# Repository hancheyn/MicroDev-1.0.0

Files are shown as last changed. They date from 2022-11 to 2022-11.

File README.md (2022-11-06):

# MicroDev Development Board Tester Setup

## Raspbian Setup
- Download Raspbian OS Imager (https://www.raspberrypi.com/software/)
- Insert and locate SD card on computer
- Install Recommended Raspberry Pi OS (w/ Software) to SD card.
- Boot-up Raspi
- Username: microdev | Password: microdev
- Connect to Internet
- Terminal: git clone https://github.com/hancheyn/MicroDev.git
- Terminal: chmod 777 MicroDev/setup.sh
- Terminal: ./MicroDev/setup.sh
- File Manager > Edit > Preferences > Volume Management > 
[uncheck] Show available options for removable media when they are inserted
- Raspberry Pi Configuration > [disable] Screen Blanking

## Arduino CLI Installation & Application
Start up raspberry pi using an hdmi monitor, keyboard, and mouse.

    Download in Add/Remove Software:
- Raspberry OS Start Menu > Preferences > Add/Remove Software
- Search “arduino”
- Check AVR development board IDE
- Check Command Line Tool for compiling Arduino Sketches
- Click Apply and Wait for Download. 

    Download in Terminal:
- Terminal: curl -fsSL https://raw.githubusercontent.com/arduino/arduino-cli/master/install.sh | sh
- Put arduino-cli into a runnable folder so the command will run on its own ($PATH).
- Terminal Command: arduino-cli core install arduino:avr
- Terminal Command View Connected Boards: arduino-cli board list
- Terminal Command Compile .ino example: arduino-cli compile -b arduino:avr:uno Blink.ino -e
- Terminal Command Upload .ino example: arduino-cli upload -b arduino:avr:uno -p /dev/ttyACM0 Blink.ino

### FLASH TO ARDUINO NOTES:
The Arduino CLI does not automatically create a permanent bit file for uploading. In order to do this, one must add the command ‘-e’ while compiling. This looks like the following: arduino-cli compile -b arduino:avr:uno Blink.ino -e.This will create a new folder within the arduino project folder that contains a bit file, “[Project name].ino.with_bootloader.bin”. This should be in a folder with a file path ./build/arduino.avr.uno/. In Terminal, the command arduino-cli upload -b arduino:avr:uno -p /dev/ttyACM0 -i [binary file path] will upload the file.
    
STM32 CLI Installation & Application
Start up raspberry pi using an hdmi monitor, keyboard, and mouse.

    Download in Add/Remove Software:
- Raspberry OS Start Menu  > Preferences > Add/Remove Software
- Search “stlink”
- Check OpenSource ST-Link tools replacement… (x3)
  - …libstlink1-1.6.1+ds-3
  - …stlink-gui-1.6.1+ds-3
  - …stlink-tools-1.6.1+ds-3

- Click Apply and Wait for Download 

### FLASH TO STM32 NOTES:
The STMCubeIDE does not automatically create a permanent bit file for uploading. Since it uses a .elf file (located in the debug folder) this must first be converted to a .bin file before flashing can occur. The .elf file can be converted using the following command from terminal arm-none-eabi-objcopy -O binary F401RE_T.elf main.bin. In the previous example, F401RE_T.elf becomes a binary file called main.bin. Flashing can then occur using the command st-flash write main.bin 0x08000000.

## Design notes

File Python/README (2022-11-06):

README

TEST CONFIGURATION
Test ID 1 => GPIO Output Voltage (under load)
Test ID 2 => GPIO Output Pin Internal Resistance
Test ID 3 => GPIO Input Pull-Up Voltage
Test ID 4 => GPIO Input Pull-Down Voltage (STM Only)
Test ID 5 => ADC Analog Read
Test ID 6 => 5.0V Supply Pin Voltage Output
Test ID 7 => 3.3V Supply Pin Voltage Output
Test ID 8 => Power Modes
Test ID 9 => Power Mode Wakeup

KEY:
E [Enable Number]
M [Mux Address]

PIN CONFIGURATION
Pin ID 1  => E1M0   | PD2 (STM)
Pin ID 2  => E1M1   | PC12 (STM)
Pin ID 3  => E1M2   | PC11 (STM)
Pin ID 4  => E1M3   | PC10 (STM)
Pin ID 5  => E1M4   | D15 (Arduino) / PB8 (STM)
Pin ID 6  => E1M5   | PC6 (STM)
Pin ID 7  => E1M6   | PC9 (STM)
Pin ID 8  => E1M7   | PC8 (STM)
Pin ID 9  => E2M0   | REF (Arduino) / IOREF (STM)
Pin ID 10 => E2M1   | BOOT0 (STM)
Pin ID 11 => E2M2   | E5V (STM)
Pin ID 12 => E2M3   | VDD (STM)
Pin ID 13 => E2M4   | AVDD (Arduino) / AVDD (STM)
Pin ID 14 => E2M5   | U5V (STM)
Pin ID 15 => E2M6   | D14 (Arduino) / PB9 (STM)
Pin ID 16 => E2M7   | PC5 (STM)
Pin ID 17 => E3M0   | PA14 (STM)
Pin ID 18 => E3M1   | 3V3 (Arduino) / +3.3 (STM)
Pin ID 19 => E3M2   | PA13 (STM)
Pin ID 20 => E3M3   | RESET (Arduino) / RESET (STM)
Pin ID 21 => E3M4   | D12 (Arduino) / PA6 (STM)
Pin ID 22 => E3M5   | PA11 (STM)
Pin ID 23 => E3M6   | D13 (Arduino) / PA5 (STM)
Pin ID 24 => E3M7   | PA12 (STM)
Pin ID 25 => E4M0   | PC13 (STM)
Pin ID 26 => E4M1   | PB7 (STM)
Pin ID 27 => E4M2   | PA15 (STM)
Pin ID 28 => E4M3   | 5V (Arduino) / +5V (STM)
Pin ID 29 => E4M4   | PB2 (STM)
Pin ID 30 => E4M5   | D10 (Arduino) / PB6 (STM)
Pin ID 31 => E4M6   | PB12 (STM)
Pin ID 32 => E4M7   | D11 (Arduino) / PA7 (STM)
Pin ID 33 => E5M0   | PC15 (STM)
Pin ID 34 => E5M1   | A0 (Arduino) / PA0 (STM)
Pin ID 35 => E5M2   | PC14 (STM)
Pin ID 36 => E5M3   | VIN (Arduino) / VIN (STM)
Pin ID 37 => E5M4   | D7 (Arduino) / PA8 (STM)
Pin ID 38 => E5M5   | PB1 (STM)
Pin ID 39 => E5M6   | D8 (Arduino) / PA9 (STM)
Pin ID 40 => E5M7   | D9 (Arduino) / PC7 (STM)
Pin ID 41 => E6M0   | PH1 (STM)
Pin ID 42 => E6M1   | A2 (Arduino) / PA4 (STM)
Pin ID 43 => E6M2   | PH0 (STM)
Pin ID 44 => E6M3   | A1 (Arduino) / PA1 (STM)
Pin ID 45 => E6M4   | D5 (Arduino) / PB4 (STM)
Pin ID 46 => E6M5   | PB14 (STM)
Pin ID 47 => E6M6   | D6 (Arduino) / PB10 (STM)
Pin ID 48 => E6M7   | PB15 (STM)
Pin ID 49 => E7M0   | PC2 (STM)
Pin ID 50 => E7M1   | A4 (Arduino) / PC1 (STM)
Pin ID 51 => E7M2   | VBAT (STM)
Pin ID 52 => E7M3   | A3 (Arduino) / PB0 (STM)
Pin ID 53 => E7M4   | D3 (Arduino) / PB3 (STM)
Pin ID 54 => E7M5   | AGND (STM)
Pin ID 55 => E7M6   | D4 (Arduino) / PB5 (STM)
Pin ID 56 => E7M7   | PB13 (STM)

Pin ID 57 => E8M2   | PC3 (STM)
Pin ID 58 => E8M3   | A5 (Arduino) / PC0 (STM)
Pin ID 59 => E8M4   | D0 (Arduino) / PA3 (STM)
Pin ID 60 => E8M5   | D1 (Arduino) / PA2 (STM)
Pin ID 61 => E8M6   | D2 (Arduino) / PA10 (STM)
Pin ID 62 => E8M7   | PC4 (STM)

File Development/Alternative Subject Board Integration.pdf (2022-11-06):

# Alternative Subject Board Integration

A top-down approach to repurposing the MicroDev code base and hardware for an unsupported subject board. WARNING: Adding or altering code may affect functionality of the MicroDev device as a whole.

## New Development Board Footprint

The MicroDev system can be adapted for a development board with less than 62 pins to be under test. In order to connect a new board, it must be made to connect through a usb port for serial communication and an adapter must be created to connect the Littlefoot to the development board footprint.

A simple way to do that would be to use an Arduino Prototyping Board as seen below, and soldering on headers to connect to the alternative development boards design:

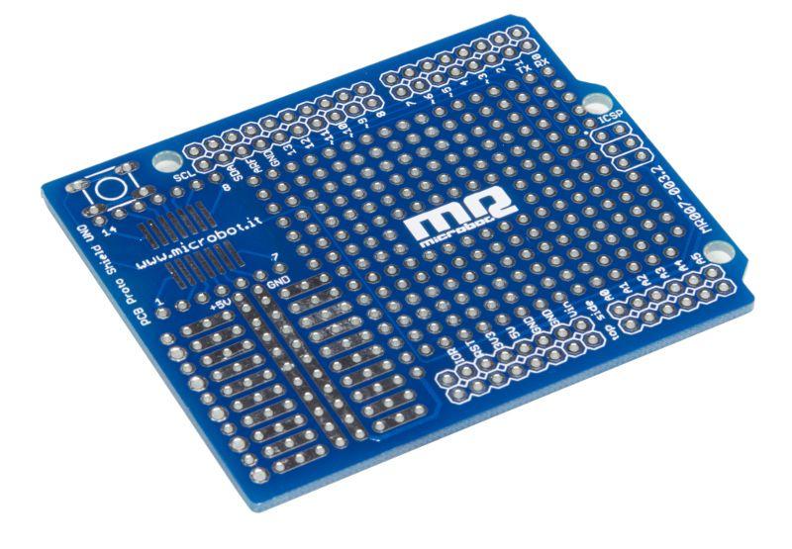
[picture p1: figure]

Figure 1: Arduino Prototyping Board

Or, a generic prototyping board to fit over the STM connection to the Littlefoot PCB on the MicroDev device.

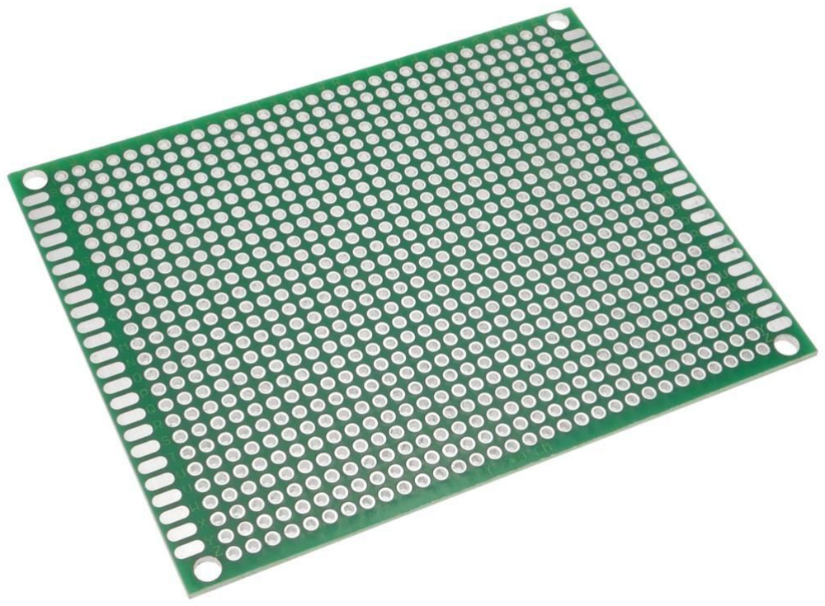
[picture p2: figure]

Figure 2: Generic PCB

### 3.3 Volt and 5 Volt Output Pin ID’s

The 3.3 Volt and 5 Volt output pins are configured to a specific multiplexer address. That means that the new footprint should connect the 3V3 pin and 5V pin of the new development board to the same place as the STM Nucleo and Arduino Uno. This could also be altered in the software by changing the functions that are contained in the Model.py module.

## Command Line Interface Alterations

If the board is an alternate STM Nucleo with the same footprint then only step the Board Identification and upload must be added in connection to the same configuration files of the other STM Nucleos. All code for the command line interface is within the Model.py module.

Board Identification and Upload

A new subject board will not be properly identified unless a command line interface compatible with the new development board is installed and configured. This command line interface must be able to identify the subject board through a unique ID, compile the embedded code, and also flash to the development board.

The identification of the connected development board is checked in a loop calling the board_list function. This function is in the Model.py module. The command line interface instruction receives an array of strings back from the subprocess call in Python. Below in Code Snippet 1, is an example of how the information is parsed to identify an Arduino Uno is connected.

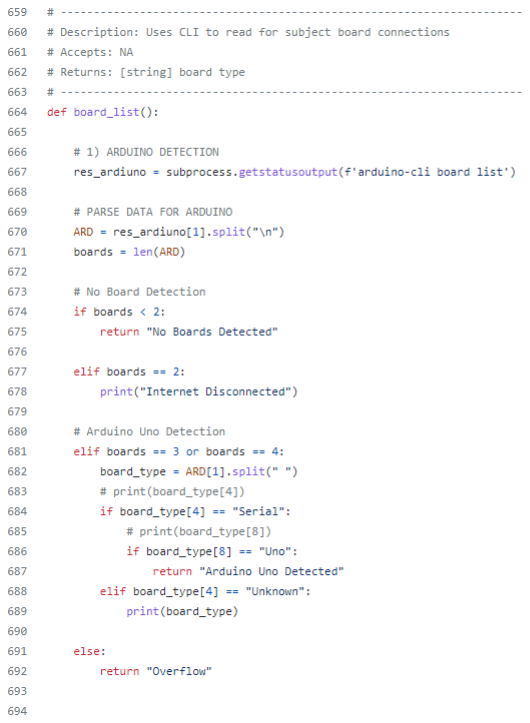
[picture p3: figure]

Code Snippet 1

The conditions for identifying the new subject board should be added after the other boards' conditionals. If nothing else is connected it will pass through those conditions and reach the connected subject board's CLI call. That should be inserted in the lines shown below in Code Snippet 2. The string that is returned after a successful detection has a place in the Controller module that is described in the pin mapping section.

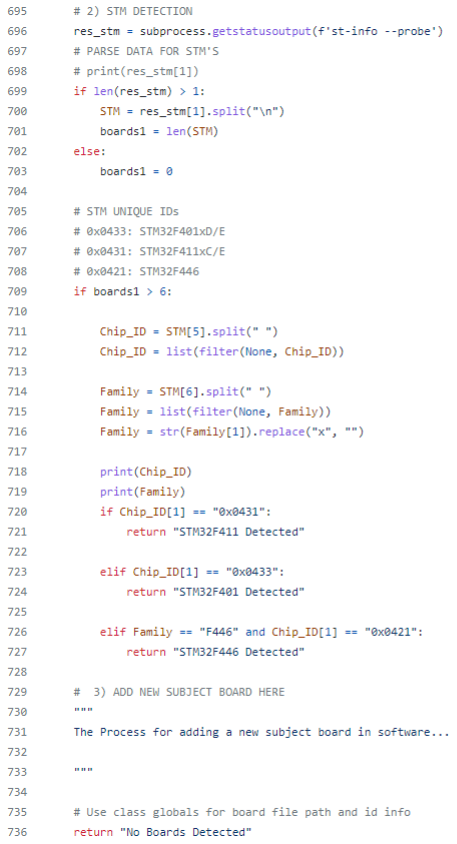
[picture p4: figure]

Code Snippet 2

## Pin Mapping and Configurations

Understanding the Pin Map

The pin map connects a pin identification number, that is used in serial communication, to the multiplexer enable signal and address signals that relate to that pin. The littlefoot PCB uses those enable signals and address signals to isolate a pin to be tested. If this pin mapping is incorrect it can be difficult to debug. The enable signals control the enable pins on each of the eight multiplexers. Only one is enabled at a time. The address signals are a 0 through 7 binary address sent via output signals to control the enabled multiplexer. The disabled multiplexer will not react to the signals even though they are all on the same bus. All code dealing with the configurations is within the Controller.py module.

Use the STM32 Nucleo Pin Map in Figure 3 as a guide to writing a new pin map.

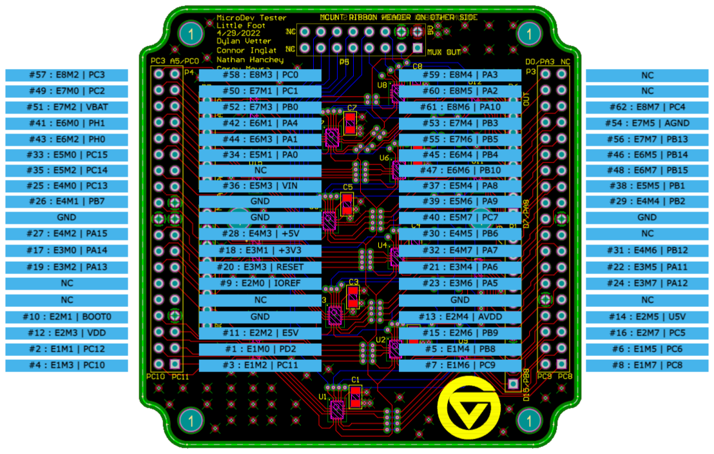
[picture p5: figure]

Figure 3: STM Nucleo Pin Mapping

The Pin IDs must be consistent between the test configuration file and the embedded C code receiving the pin ID value.

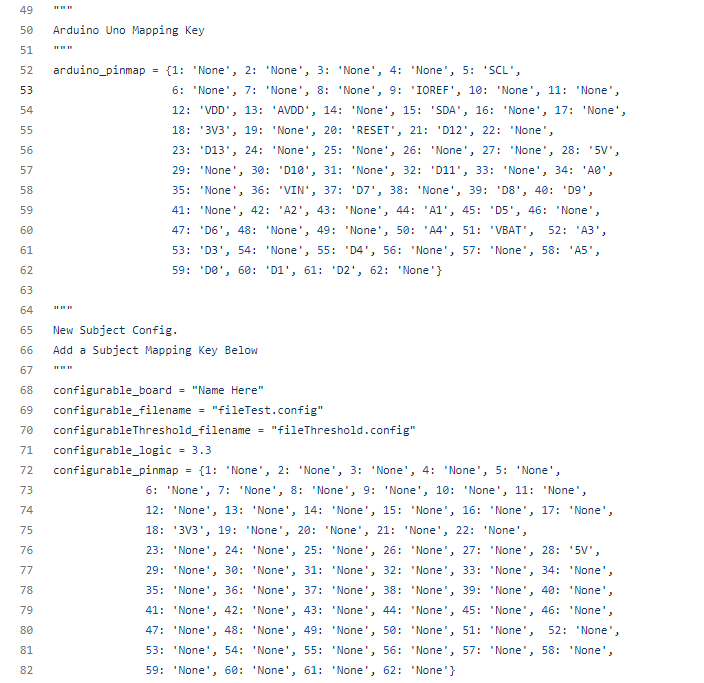
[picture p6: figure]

Code Snippet 3

The string configurable_board, seen in Code Snippet 3, must be the same string that is returned from the board_list function added in Model.py. The high logic level of the new subject development board is to be written as the configurable_logic. The string for the threshold filename, configurableThreshold_filename, and test filenames, configurable_filename, must exist in the project Python folder.

The threshold file is setup as follows:

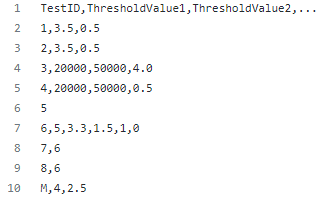
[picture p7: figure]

Code Snippet 4

After the first line, each following line is the test thresholds that will be used as the pass or fail conditions of the test. The first line describes the threshold configuration format, an improperly formatted threshold file will end the testing process. Every line shown above must be in the threshold file just as shown in Code Snippet 4. The second line represents Test #1 and each following line must be the next consecutive Test ID. M, or miscellaneous, goes on line 10. The thresholds values are as follows:

Test #1 | Min High Voltage | Max Low Voltage
Test #2 | Min High Voltage | Max Low Voltage
Test #3 | Min Resistance | | Max Resistance | | Pull-Up Min Voltage
Test #4 | Min Resistance | | Max Resistance | | Pull_Down Max Voltage
Test #5 | N/A
Test #6 | Voltages Generated By DAC (works on a loop based on length of array)
Test #7 | Current Drop mA (initial - final)
Test #8 | Current Drop mA (final - initial)
Misc. | | 5V Pin Minimum Voltage | | 3V3 Pin Minimum Voltage

The test file is setup as follows:

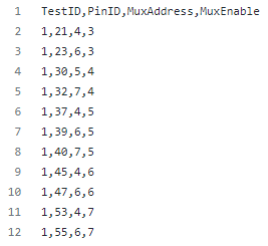
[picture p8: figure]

Code Snippet 5

After the first line, each following line is a test that will be conducted. The first line describes the test configuration format, shown in Code Snippet 5. An improperly formatted test file will end the test before finishing. The Test ID and Pin ID that is recognized by the subject development board goes first. Then, the Multiplexer Address and Enable pin comes next, all separated by commas. It is important to remember the pin ID must go with the address and enable value for that pin. The exception is with tests #7 and #8. Test #7 does not need the address and enable value and Test #8 has a preconfigured wakeup pin depending on the subject board.

## Subject Board Embedded Code

Code Model for Serial Communication Data Packets

There are a few functions that must be altered in order to use the MicroDev code base for a new development board. The main must also be altered for initializations unique to the development board and for receiving serial data. The additional functions that must be replaced or written are as follows:

Main.c
int command_read(unsigned char data[]);
int command_write(unsigned int pin, unsigned int result, unsigned int test); int analogRead(int pin);
int digitalRead(int pin);
void analogWrite(int pin, int value);
void digitalWrite(int pin, int logic); void pinMode(int pin, int mode);

void configure_sleep_mode(unsigned int sleepmode, unsigned int interruptPin); void wakeUp();

Setup.c
struct pin pin_set(uint32_t pin, uint32_t clock, GPIO_TypeDef * gpio, uint8_t pin_id); void init_pins(struct pin pins[]);

Within the Development folder of the MicroDev directory, there are C files to get a jumpstart with developing the new embedded code for the MicroDev system.

The following model demonstrates how to wait for serial communication on the subject board. Additionally, a method of establishing a pin mapping in the embedded code is referenced. Below is a pseudocode example of the STM32 code used to wait for serial communication for the next test.

INITIALIZE pin map
MAIN LOOP

IF serial message received
Read message
IF message passes decoding IF normal test
Run Test
Write serial message with results
ELSE IF facade test
Write serial message with pin register value

Pin Configurations and Setup

Use default configurations, auto-generated code, or the hardware abstraction layer to assist with configuring pins or power modes, if applicable.

The pins must also be identified on the subject development board to run each test. One way of doing that is to create a structure in the embedded code that has the important register values and use the index as the pin ID value, as seen in Code Snippet 7.

struct pin pin_set(uint32_t pin, uint32_t clock, GPIO_TypeDef * gpio, uint8_t pin_id) {

struct pin P;
P.pin = pin;
P.pin_id = pin_id;

P.clock = clock;

P.GPIO = gpio;

return P;
}

// Initialize pin struct array
void init_pins(struct pin pins[]) {
// Pin 0 Example | PA5
pins[0] = pin_set(0x05, 0x01, GPIOA, 0);
// Pin 1 | PD2
pins[1] = pin_set(0x02, 0x08, GPIOD, 1);
// Pin 2 | PC12
pins[2] = pin_set(0x0C, 0x04, GPIOC, 2);
// Pin 3 | PC11
pins[3] = pin_set(0x0B, 0x04, GPIOC, 3);

…
}

Code Snippet 7

Test Inputs and Outputs

The following figure, Figure 4, describes what is generally communicated through serial communication.

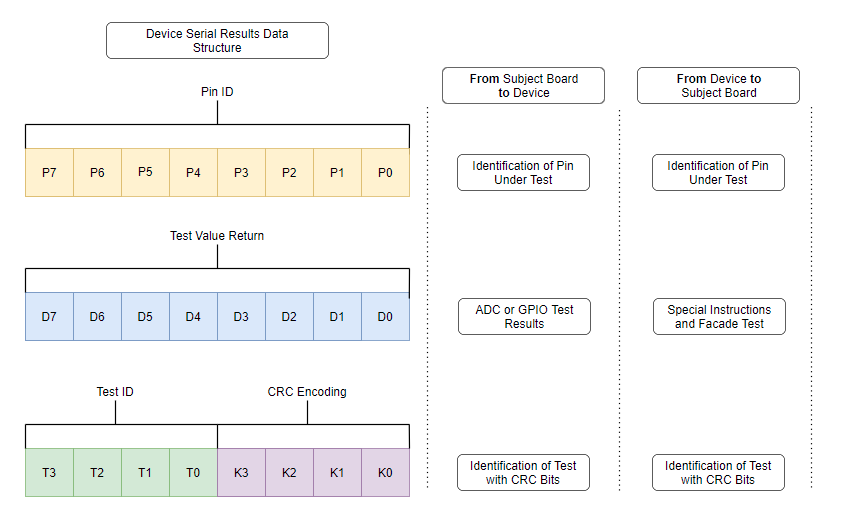
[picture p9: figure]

Figure 4: Serial Communication Data Packets

Specifically, each test has its own Test ID value and some of them return a measurement in an 8-bit number. A description of this is below.

Output Test #1 - Sets Voltage with no returned measurement

Output Test Under Load #2 - Sets Voltage with no returned measurement

Input Pull Up Test #3 - Sets Voltage with no returned measurement

Input Pull Down Test #4 - Sets Voltage with no returned measurement

Input Logic Test #5 - Sets Input and Returns a 1 or 0 for High or Low digital signal.

Analog to Digital Converter Test #6 - Sets ADC input and return value shifted to 8 bits.

Power Mode Test #7 - Sets Power Mode and returns nothing

Wakeup Test #8 - Wakes up for low power mode

Testing and Verifying New Code
Refer back to software verification in the design document.

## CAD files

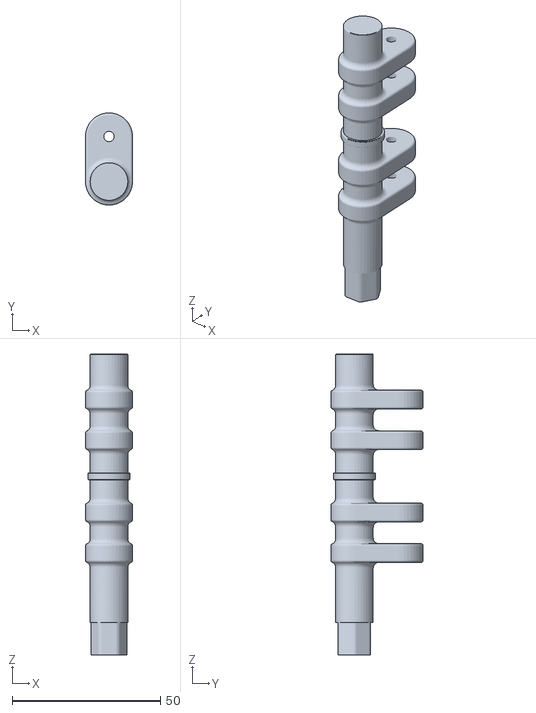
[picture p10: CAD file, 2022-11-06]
MDT0000_STLs_V20_/MDTM4003.STL
15.9 x 31.1 x 101.6

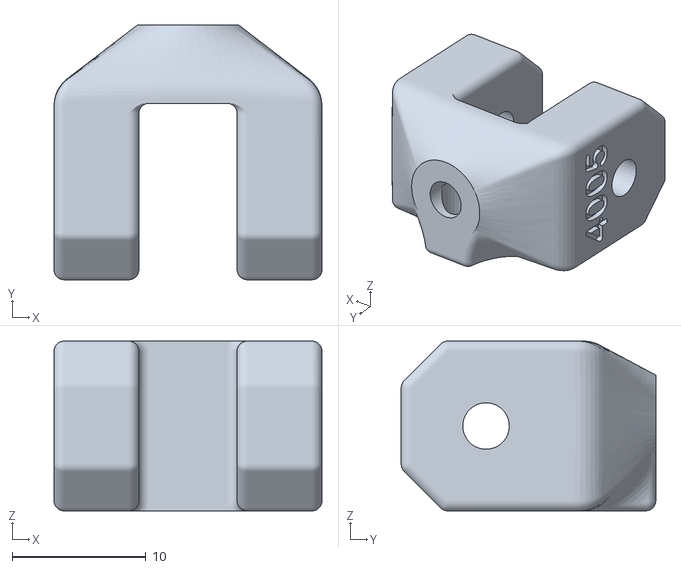
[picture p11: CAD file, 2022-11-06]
MDT0000_STLs_V20_/MDTM4005.STL
20.1 x 19.1 x 12.7

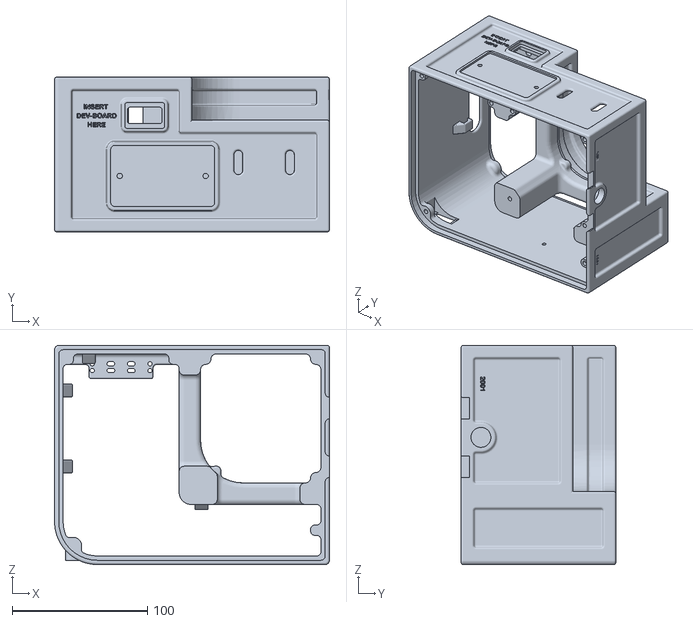
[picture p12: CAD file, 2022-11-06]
MDT0000_STLs_V20_/MDTM0000.STL
203.2 x 114.3 x 161.9

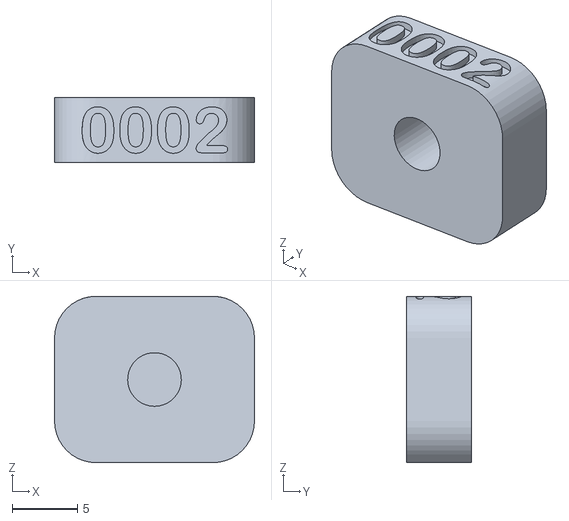
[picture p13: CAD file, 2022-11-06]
MDT0000_STLs_V20_/MDTM0002.STL
15.3 x 5.00 x 12.7

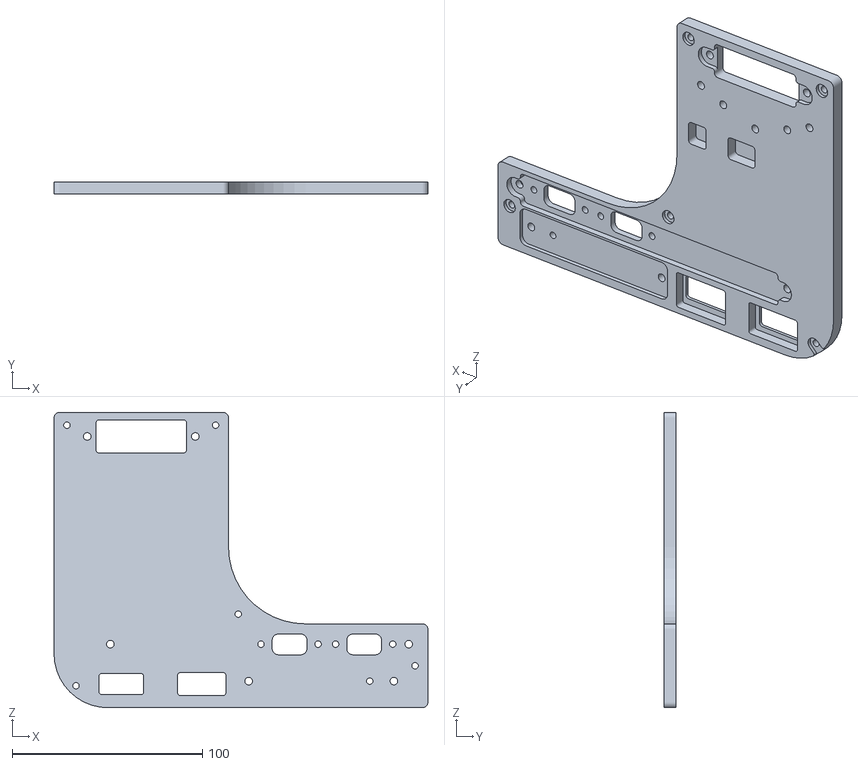
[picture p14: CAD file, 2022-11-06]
MDT0000_STLs_V20_/MDTM1002.STL
196.4 x 6.35 x 155.2

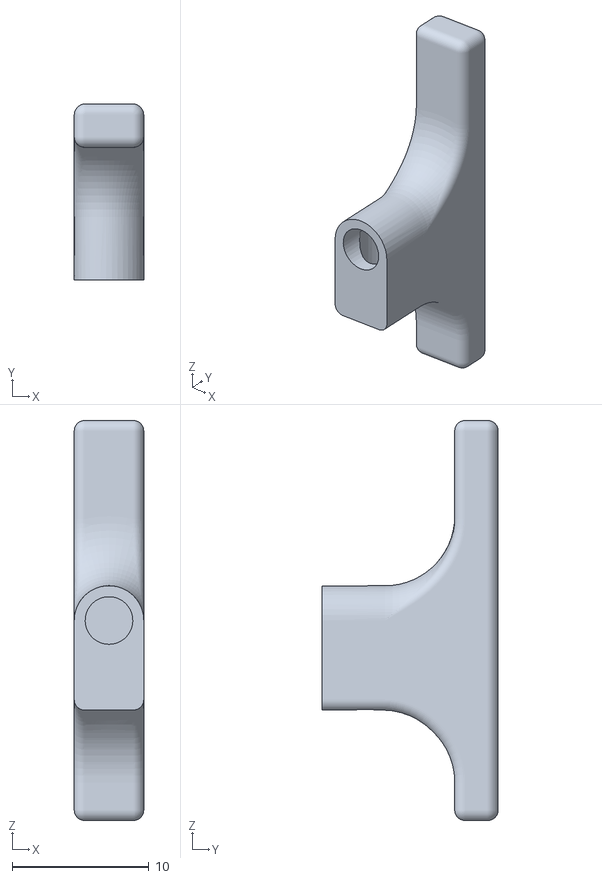
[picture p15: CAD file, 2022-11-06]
MDT0000_STLs_V20_/MDTM4007.STL
5.08 x 12.9 x 29.2

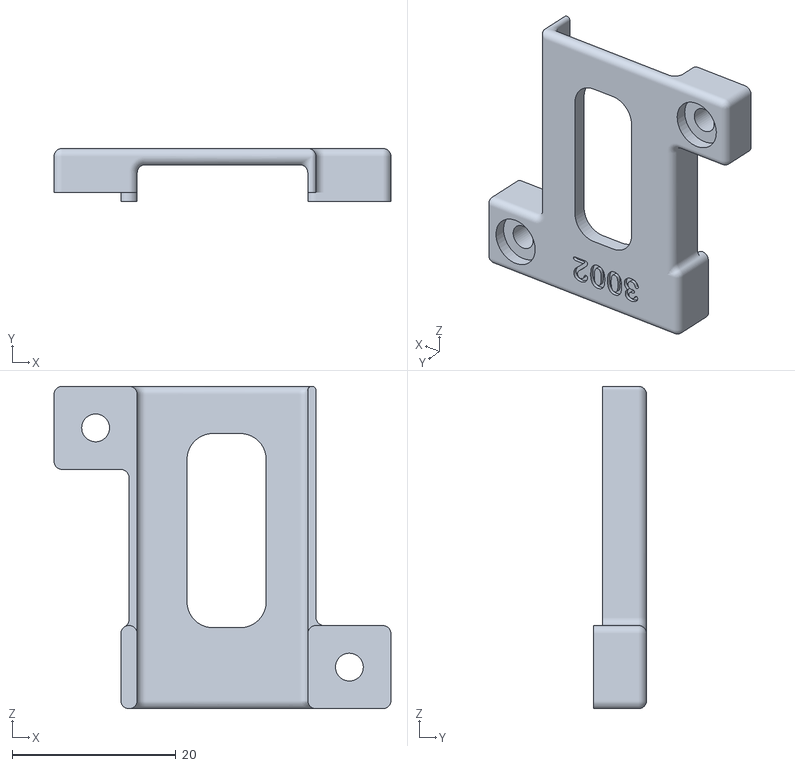
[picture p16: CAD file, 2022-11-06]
MDT0000_STLs_V20_/MDTM3002.STL
41.1 x 6.50 x 39.4

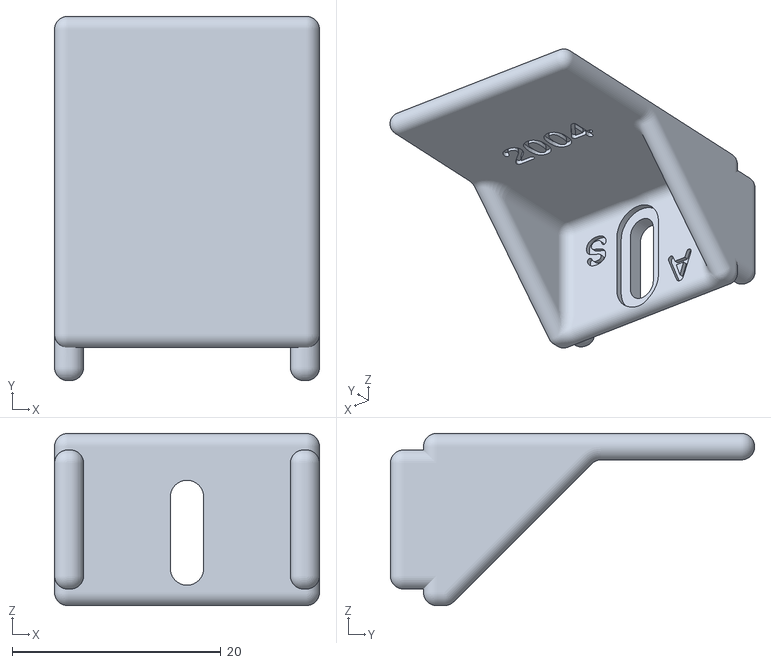
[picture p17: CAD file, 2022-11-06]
MDT0000_STLs_V20_/MDTM2005.STL
25.4 x 34.9 x 16.5

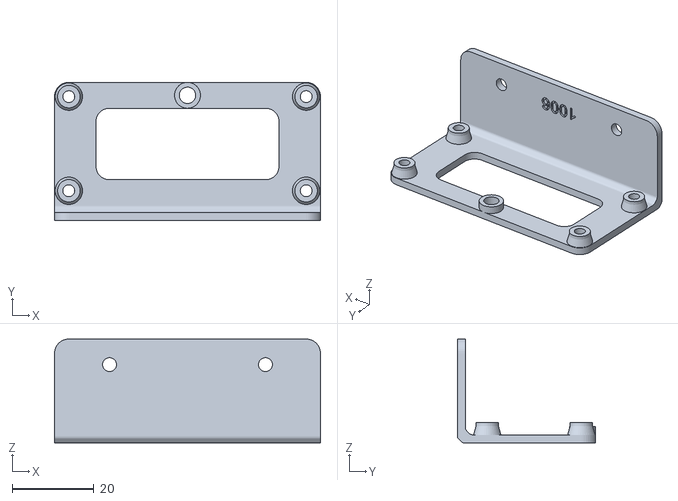
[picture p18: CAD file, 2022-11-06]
MDT0000_STLs_V20_/MDTM1006.STL
65.0 x 33.8 x 25.4

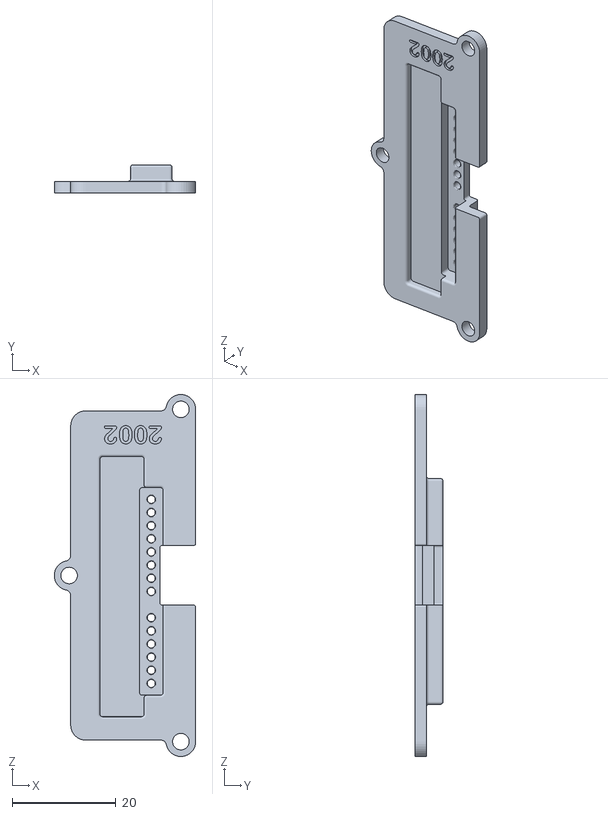
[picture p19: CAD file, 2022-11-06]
MDT0000_STLs_V20_/MDTM2003_ARD.STL
27.3 x 5.49 x 69.9

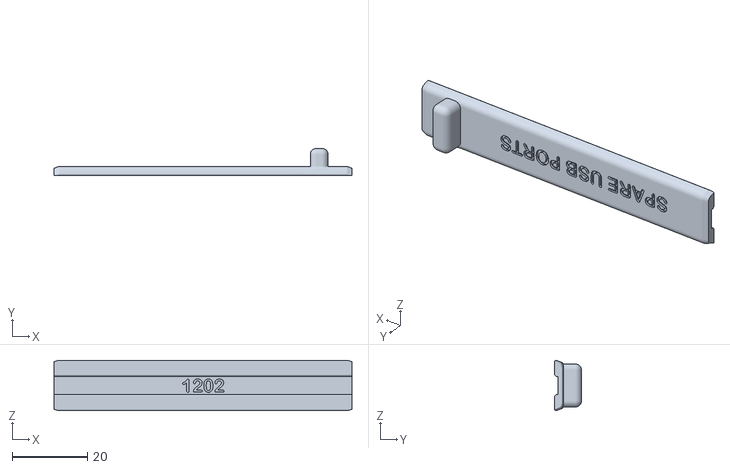
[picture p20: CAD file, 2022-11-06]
MDT0000_STLs_V20_/MDTM1202.STL
79.4 x 7.20 x 13.4

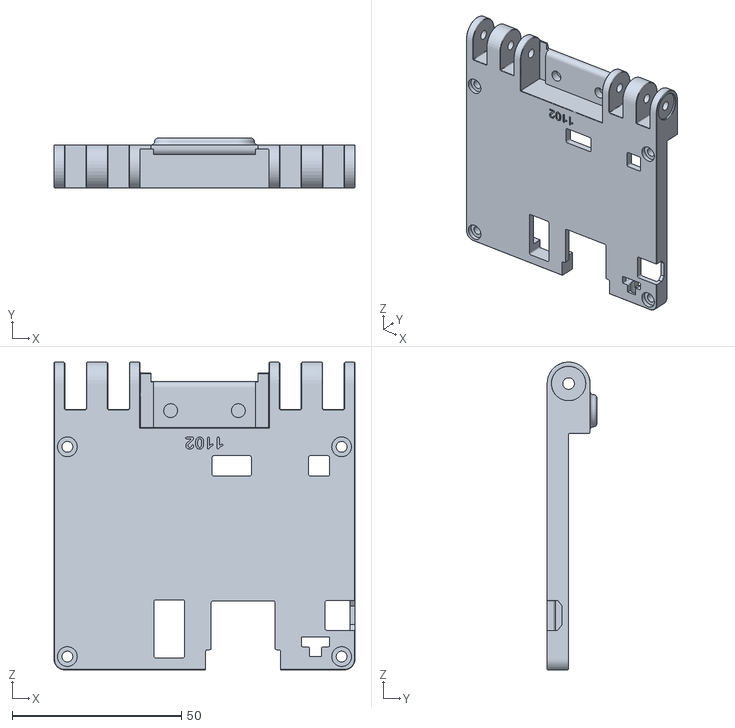
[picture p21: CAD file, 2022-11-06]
MDT0000_STLs_V20_/MDTM1102.STL
88.9 x 14.7 x 90.9

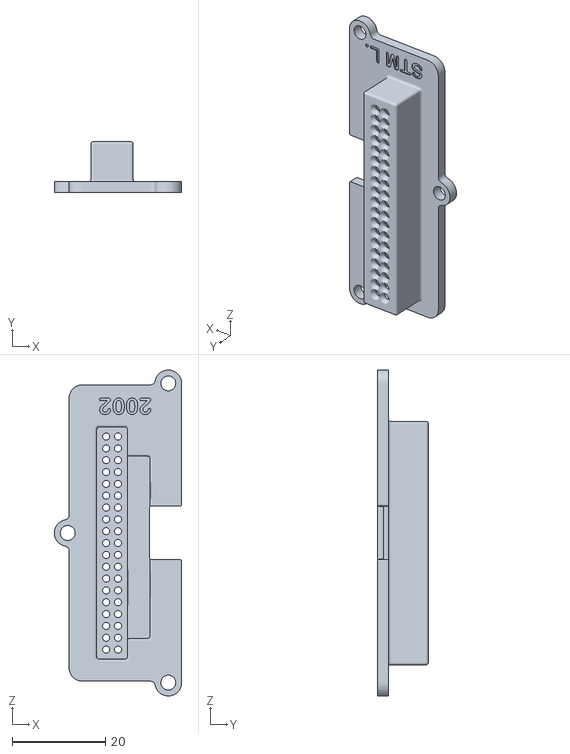
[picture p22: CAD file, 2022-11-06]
MDT0000_STLs_V20_/MDTM2003_STM.STL
27.3 x 10.9 x 69.9

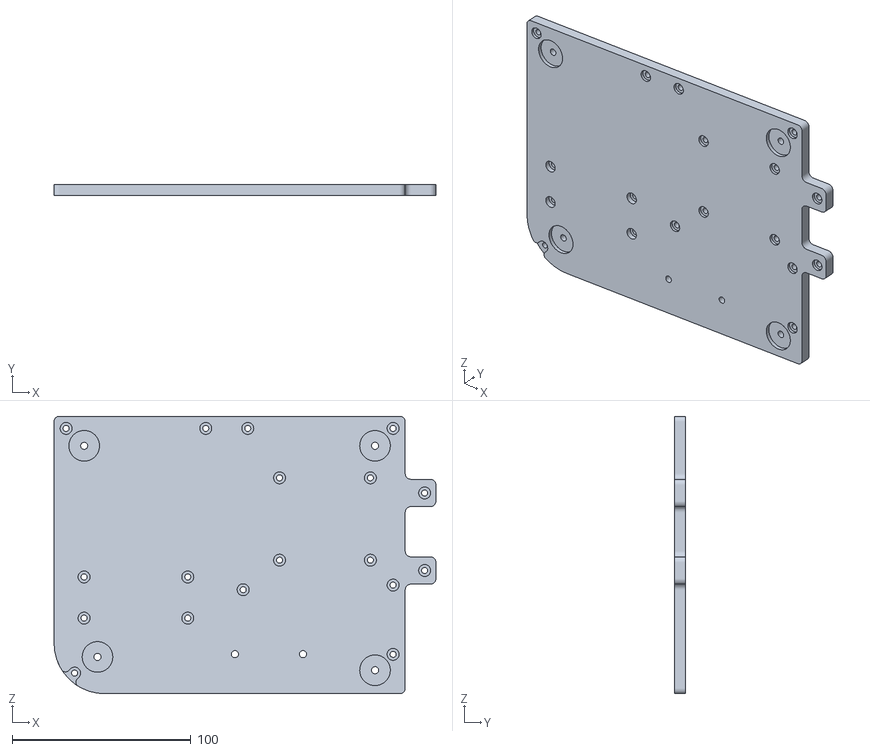
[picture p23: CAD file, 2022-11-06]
MDT0000_STLs_V20_/MDTM0001.STL
213.7 x 6.35 x 155.2

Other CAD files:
MDT0000_STLs_V20_/MDTM1103.STL
MDT0000_STLs_V20_/MDTM1201.STL
MDT0000_STLs_V20_/MDTM4001.STL
MDT0000_STLs_V20_/MDTM4002.STL
MDT0000_STLs_V20_/MDTM0003.STL
MDT0000_STLs_V20_/MDTM1004.STL
MDT0000_STLs_V20_/MDTM1008.STL
MDT0000_STLs_V20_/MDTM1101.STL
MDT0000_STLs_V20_/MDTM1104.STL
MDT0000_STLs_V20_/MDTM2002.STL
MDT0000_STLs_V20_/MDTM2004_ARD.STL
MDT0000_STLs_V20_/MDTM2004_STM.STL
MDT0000_STLs_V20_/MDTM3001.STL
MDT0000_STLs_V20_/MDTM4004.STL
MDT0000_STLs_V20_/MDTM4008.STL
MDT0000_STLs_V20_/MDTM4009.STL

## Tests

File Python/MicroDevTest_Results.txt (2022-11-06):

Detailed Test Results
Test #1 Pin #21 Result: Failed
Test #1 Pin #23 Result: Failed
Test #1 Pin #30 Result: Failed
Test #1 Pin #32 Result: Failed
Test #1 Pin #37 Result: Failed
Test #1 Pin #39 Result: Failed
Test #1 Pin #40 Result: Failed
Test #1 Pin #45 Result: Failed
Test #1 Pin #47 Result: Failed
Test #1 Pin #53 Result: Failed
Test #1 Pin #55 Result: Failed
Test #1 Pin #61 Result: Failed
Test #1 Pin #34 Result: Passed
Test #1 Pin #44 Result: Passed
Test #1 Pin #42 Result: Passed
Test #1 Pin #52 Result: Passed
Test #1 Pin #50 Result: Passed
Test #1 Pin #58 Result: Passed
Test #2 Pin #21 Result: Failed
Test #2 Pin #23 Result: Failed
Test #2 Pin #30 Result: Failed
Test #2 Pin #32 Result: Failed
Test #2 Pin #37 Result: Failed
Test #2 Pin #39 Result: Failed
Test #2 Pin #40 Result: Failed
Test #2 Pin #45 Result: Failed
Test #2 Pin #47 Result: Failed
Test #2 Pin #53 Result: Failed
Test #2 Pin #55 Result: Failed
Test #2 Pin #61 Result: Failed
Test #2 Pin #34 Result: Passed
Test #2 Pin #44 Result: Passed
Test #2 Pin #42 Result: Passed
Test #2 Pin #52 Result: Passed
Test #2 Pin #50 Result: Passed
Test #2 Pin #58 Result: Passed
Test #3 Pin #21 Result: Failed
Test #3 Pin #23 Result: Failed
Test #3 Pin #30 Result: Failed
Test #3 Pin #32 Result: Failed
Test #3 Pin #37 Result: Failed
Test #3 Pin #39 Result: Failed
Test #3 Pin #40 Result: Failed
Test #3 Pin #45 Result: Failed
Test #3 Pin #47 Result: Failed
Test #3 Pin #53 Result: Failed
Test #3 Pin #55 Result: Failed
Test #3 Pin #61 Result: Failed
Test #3 Pin #34 Result: Passed
Test #3 Pin #44 Result: Passed
Test #3 Pin #42 Result: Passed
Test #3 Pin #52 Result: Passed
Test #3 Pin #50 Result: Passed
Test #3 Pin #58 Result: Passed
Test #5 Pin #21 Result: Failed
Test #5 Pin #23 Result: Failed
Test #5 Pin #30 Result: Failed
Test #5 Pin #32 Result: Failed
Test #5 Pin #37 Result: Failed
Test #5 Pin #39 Result: Failed
Test #5 Pin #40 Result: Failed
Test #5 Pin #45 Result: Failed
Test #5 Pin #47 Result: Failed
Test #5 Pin #53 Result: Failed
Test #5 Pin #55 Result: Failed
Test #5 Pin #61 Result: Failed
Test #5 Pin #34 Result: Passed
Test #5 Pin #44 Result: Passed
Test #5 Pin #42 Result: Passed
Test #5 Pin #52 Result: Passed
Test #5 Pin #50 Result: Passed
Test #5 Pin #58 Result: Passed
Test #6 Pin #34 Result: Passed
Test #6 Pin #44 Result: Passed
Test #6 Pin #42 Result: Passed
Test #6 Pin #52 Result: Passed
Test #6 Pin #50 Result: Passed
Test #6 Pin #58 Result: Passed
Test #7 Pin #1 Result: Passed
Test #8 Pin #1 Result: Failed
Test #7 Pin #2 Result: Failed
Test #8 Pin #2 Result: Failed
Test #7 Pin #3 Result: Failed
Test #8 Pin #3 Result: Failed
Test #7 Pin #4 Result: Failed
Test #8 Pin #4 Result: Failed
Test #7 Pin #5 Result: Failed
Test #8 Pin #5 Result: Failed
Test #7 Pin #6 Result: Failed
Test #8 Pin #6 Result: Failed

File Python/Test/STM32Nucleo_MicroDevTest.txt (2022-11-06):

Test 1: Output without Load
Test Logic High: 3.36 V
Test Logic Low: 0.0 V
Above results for Pin ID PD2

Test 1: Output without Load
Test Logic High: 3.37 V
Test Logic Low: 0.0 V
Above results for Pin ID PC12

Test 1: Output without Load
Test Logic High: 3.37 V
Test Logic Low: 0.0 V
Above results for Pin ID PC11

Test 1: Output without Load
Test Logic High: 3.37 V
Test Logic Low: 0.0 V
Above results for Pin ID PC10

Test 1: Output without Load
Test Logic High: 3.36 V
Test Logic Low: 0.0 V
Above results for Pin ID PB8

Test 1: Output without Load
Test Logic High: 3.37 V
Test Logic Low: 0.0 V
Above results for Pin ID PC6

Test 1: Output without Load
Test Logic High: 3.37 V
Test Logic Low: 0.0 V
Above results for Pin ID PC9

Test 1: Output without Load
Test Logic High: 3.35 V
Test Logic Low: 0.0 V
Above results for Pin ID PC8

Test 1: Output without Load
Test Logic High: 3.35 V
Test Logic Low: 0.0 V
Above results for Pin ID PB9

Test 1: Output without Load
Test Logic High: 3.38 V
Test Logic Low: 0.0 V
Above results for Pin ID PC5

Test 1: Output without Load
Test Logic High: 3.37 V
Test Logic Low: 0.0 V
Above results for Pin ID PA6

Test 1: Output without Load
Test Logic High: 3.36 V
Test Logic Low: 0.0 V
Above results for Pin ID PA11

Test 1: Output without Load
Test Logic High: 3.32 V
Test Logic Low: 0.0 V
Above results for Pin ID PA5

Test 1: Output without Load
Test Logic High: 3.37 V
Test Logic Low: 0.01 V
Above results for Pin ID PA12

Test 1: Output without Load
Test Logic High: 3.37 V
Test Logic Low: 0.02 V
Above results for Pin ID PC13

Test 1: Output without Load
Test Logic High: 3.37 V
Test Logic Low: 0.0 V
Above results for Pin ID PB7

Test 1: Output without Load
Test Logic High: 3.35 V
Test Logic Low: 0.01 V
Above results for Pin ID PA15

Test 1: Output without Load
Test Logic High: 3.35 V
Test Logic Low: 0.0 V
Above results for Pin ID PB2

Test 1: Output without Load
Test Logic High: 3.36 V
Test Logic Low: 0.0 V
Above results for Pin ID PB6

Test 1: Output without Load
Test Logic High: 3.37 V
Test Logic Low: 0.01 V
Above results for Pin ID PB12

Test 1: Output without Load
Test Logic High: 3.36 V
Test Logic Low: 0.0 V
Above results for Pin ID PA7

Test 1: Output without Load
Test Logic High: 3.37 V
Test Logic Low: 0.0 V
Above results for Pin ID PA0

Test 1: Output without Load
Test Logic High: 3.37 V
Test Logic Low: 0.0 V
Above results for Pin ID PA8

Test 1: Output without Load
Test Logic High: 3.36 V
Test Logic Low: 0.0 V
Above results for Pin ID PB1

Test 1: Output without Load
Test Logic High: 3.37 V
Test Logic Low: 0.0 V
Above results for Pin ID PA9

Test 1: Output without Load
Test Logic High: 3.37 V
Test Logic Low: 0.0 V
Above results for Pin ID PC7

Test 1: Output without Load
Test Logic High: 3.37 V
Test Logic Low: 0.0 V
Above results for Pin ID PA4

Test 1: Output without Load
Test Logic High: 3.35 V
Test Logic Low: 0.0 V
Above results for Pin ID PA1

Test 1: Output without Load
Test Logic High: 3.36 V
Test Logic Low: 0.01 V
Above results for Pin ID PB4

Test 1: Output without Load
Test Logic High: 3.38 V
Test Logic Low: 0.01 V
Above results for Pin ID PB14

Test 1: Output without Load
Test Logic High: 3.35 V
Test Logic Low: 0.0 V
Above results for Pin ID PB10

Test 1: Output without Load
Test Logic High: 3.35 V
Test Logic Low: 0.01 V
Above results for Pin ID PB15

Test 1: Output without Load
Test Logic High: 3.35 V
Test Logic Low: 0.0 V
Above results for Pin ID PC2

Test 1: Output without Load
Test Logic High: 3.35 V
Test Logic Low: 0.0 V
Above results for Pin ID PC1

Test 1: Output without Load
Test Logic High: 3.36 V
Test Logic Low: 0.0 V
Above results for Pin ID PB0

Test 1: Output without Load
Test Logic High: 3.36 V
Test Logic Low: 0.0 V
Above results for Pin ID PB3

Test 1: Output without Load
Test Logic High: 3.38 V
Test Logic Low: 0.0 V
Above results for Pin ID PB5

Test 1: Output without Load
Test Logic High: 3.37 V
Test Logic Low: 0.01 V
Above results for Pin ID PB13

Test 1: Output without Load
Test Logic High: 3.36 V
Test Logic Low: 0.0 V
Above results for Pin ID PC3

Test 1: Output without Load
Test Logic High: 3.35 V
Test Logic Low: 0.0 V
Above results for Pin ID PC0

Test 1: Output without Load
Test Logic High: 3.35 V
Test Logic Low: 0.0 V
Above results for Pin ID PA10

Test 1: Output without Load
Test Logic High: 3.35 V
Test Logic Low: 0.0 V
Above results for Pin ID PC4

Test 2: Output w/ Load
Test Logic High: 3.17 V
Test Logic Low: 0.0 V
Above results for Pin ID PD2

Test 2: Output w/ Load
Test Logic High: 3.17 V
Test Logic Low: 0.0 V
Above results for Pin ID PC12

Test 2: Output w/ Load
Test Logic High: 3.17 V
Test Logic Low: 0.0 V
Above results for Pin ID PC11

Test 2: Output w/ Load
Test Logic High: 3.18 V
Test Logic Low: 0.0 V
Above results for Pin ID PC10

Test 2: Output w/ Load
Test Logic High: 3.17 V
Test Logic Low: 0.0 V
Above results for Pin ID PB8

Test 2: Output w/ Load
Test Logic High: 3.17 V
Test Logic Low: 0.0 V
Above results for Pin ID PC6

Test 2: Output w/ Load
Test Logic High: 3.17 V
Test Logic Low: 0.0 V
Above results for Pin ID PC9

Test 2: Output w/ Load
Test Logic High: 3.16 V
Test Logic Low: 0.0 V
Above results for Pin ID PC8

Test 2: Output w/ Load
Test Logic High: 3.17 V
Test Logic Low: 0.0 V
Above results for Pin ID PB9

Test 2: Output w/ Load
Test Logic High: 3.17 V
Test Logic Low: 0.0 V
Above results for Pin ID PC5

Test 2: Output w/ Load
Test Logic High: 3.17 V
Test Logic Low: 0.0 V
Above results for Pin ID PA6

Test 2: Output w/ Load
Test Logic High: 3.15 V
Test Logic Low: 0.0 V
Above results for Pin ID PA11

Test 2: Output w/ Load
Test Logic High: 3.13 V
Test Logic Low: 0.0 V
Above results for Pin ID PA5

Test 2: Output w/ Load
Test Logic High: 3.16 V
Test Logic Low: 0.0 V
Above results for Pin ID PA12

Test 2: Output w/ Load
Test Logic High: 3.03 V
Test Logic Low: 0.02 V
Above results for Pin ID PC13

Test 2: Output w/ Load
Test Logic High: 3.17 V
Test Logic Low: 0.0 V
Above results for Pin ID PB7

Test 2: Output w/ Load
Test Logic High: 3.18 V
Test Logic Low: 0.01 V
Above results for Pin ID PA15

Test 2: Output w/ Load
Test Logic High: 3.17 V
Test Logic Low: 0.0 V
Above results for Pin ID PB2

Test 2: Output w/ Load
Test Logic High: 3.18 V
Test Logic Low: 0.0 V
Above results for Pin ID PB6

Test 2: Output w/ Load
Test Logic High: 3.17 V
Test Logic Low: 0.0 V
Above results for Pin ID PB12

Test 2: Output w/ Load
Test Logic High: 3.17 V
Test Logic Low: 0.0 V
Above results for Pin ID PA7

Test 2: Output w/ Load
Test Logic High: 3.16 V
Test Logic Low: 0.0 V
Above results for Pin ID PA0

Test 2: Output w/ Load
Test Logic High: 3.17 V
Test Logic Low: 0.0 V
Above results for Pin ID PA8

Test 2: Output w/ Load
Test Logic High: 3.17 V
Test Logic Low: 0.0 V
Above results for Pin ID PB1

Test 2: Output w/ Load
Test Logic High: 3.17 V
Test Logic Low: 0.0 V
Above results for Pin ID PA9

Test 2: Output w/ Load
Test Logic High: 3.17 V
Test Logic Low: 0.0 V
Above results for Pin ID PC7

Test 2: Output w/ Load
Test Logic High: 3.17 V
Test Logic Low: 0.0 V
Above results for Pin ID PA4

Test 2: Output w/ Load
Test Logic High: 3.18 V
Test Logic Low: 0.0 V
Above results for Pin ID PA1

Test 2: Output w/ Load
Test Logic High: 3.17 V
Test Logic Low: 0.01 V
Above results for Pin ID PB4

Test 2: Output w/ Load
Test Logic High: 3.17 V
Test Logic Low: 0.0 V
Above results for Pin ID PB14

Test 2: Output w/ Load
Test Logic High: 3.19 V
Test Logic Low: 0.0 V
Above results for Pin ID PB10

Test 2: Output w/ Load
Test Logic High: 3.17 V
Test Logic Low: 0.0 V
Above results for Pin ID PB15

Test 2: Output w/ Load
Test Logic High: 3.17 V
Test Logic Low: 0.0 V
Above results for Pin ID PC2

Test 2: Output w/ Load
Test Logic High: 3.16 V
Test Logic Low: 0.0 V
Above results for Pin ID PC1

Test 2: Output w/ Load
Test Logic High: 3.18 V
Test Logic Low: 0.0 V
Above results for Pin ID PB0

Test 2: Output w/ Load
Test Logic High: 3.17 V
Test Logic Low: 0.0 V
Above results for Pin ID PB3

Test 2: Output w/ Load
Test Logic High: 3.18 V
Test Logic Low: 0.0 V
Above results for Pin ID PB5

Test 2: Output w/ Load
Test Logic High: 3.17 V
Test Logic Low: 0.0 V
Above results for Pin ID PB13

Test 2: Output w/ Load
Test Logic High: 3.17 V
Test Logic Low: 0.0 V
Above results for Pin ID PC3

Test 2: Output w/ Load
Test Logic High: 3.16 V
Test Logic Low: 0.0 V
Above results for Pin ID PC0

Test 2: Output w/ Load
Test Logic High: 3.17 V
Test Logic Low: 0.0 V
Above results for Pin ID PA10

Test 2: Output w/ Load
Test Logic High: 3.18 V
Test Logic Low: 0.0 V
Above results for Pin ID PC4

Test 3: Pull-Up Input
Test Pull Up Resistance Value: 41.0k ohms
Above results for Pin ID PD2

Test 3: Pull-Up Input
Test Pull Up Resistance Value: 41.0k ohms
Above results for Pin ID PC12

Test 3: Pull-Up Input
Test Pull Up Resistance Value: 41.0k ohms
Above results for Pin ID PC11

Test 3: Pull-Up Input
Test Pull Up Resistance Value: 41.0k ohms
Above results for Pin ID PC10

Test 3: Pull-Up Input
Test Pull Up Resistance Value: 41.0k ohms
Above results for Pin ID PB8

Test 3: Pull-Up Input
Test Pull Up Resistance Value: 41.0k ohms
Above results for Pin ID PC6

Test 3: Pull-Up Input
Test Pull Up Resistance Value: 41.0k ohms
Above results for Pin ID PC9

Test 3: Pull-Up Input
Test Pull Up Resistance Value: 41.0k ohms
Above results for Pin ID PC8

Test 3: Pull-Up Input
Test Pull Up Resistance Value: 41.0k ohms
Above results for Pin ID PB9

Test 3: Pull-Up Input
Test Pull Up Resistance Value: 41.0k ohms
Above results for Pin ID PC5

Test 3: Pull-Up Input
Test Pull Up Resistance Value: 41.0k ohms
Above results for Pin ID PA6

Test 3: Pull-Up Input
Test Pull Up Resistance Value: 41.0k ohms
Above results for Pin ID PA11

Test 3: Pull-Up Input
Test Pull Up Resistance Value: 41.0k ohms
Above results for Pin ID PA12

Test 3: Pull-Up Input
Test Pull Up Resistance Value: 41.0k ohms
Above results for Pin ID PB7

Test 3: Pull-Up Input
Test Pull Up Resistance Value: 41.0k ohms
Above results for Pin ID PA15

Test 3: Pull-Up Input
Test Pull Up Resistance Value: 41.0k ohms
Above results for Pin ID PB2

Test 3: Pull-Up Input
Test Pull Up Resistance Value: 41.0k ohms
Above results for Pin ID PB6

Test 3: Pull-Up Input
Test Pull Up Resistance Value: 9.0k ohms
Above results for Pin ID PB12

Test 3: Pull-Up Input
Test Pull Up Resistance Value: 41.0k ohms
Above results for Pin ID PA7

Test 3: Pull-Up Input
Test Pull Up Resistance Value: 41.0k ohms
Above results for Pin ID PA0

Test 3: Pull-Up Input
Test Pull Up Resistance Value: 41.0k ohms
Above results for Pin ID PA8

Test 3: Pull-Up Input
Test Pull Up Resistance Value: 41.0k ohms
Above results for Pin ID PB1

Test 3: Pull-Up Input
Test Pull Up Resistance Value: 41.0k ohms
Above results for Pin ID PA9

Test 3: Pull-Up Input
Test Pull Up Resistance Value: 41.0k ohms
Above results for Pin ID PC7

Test 3: Pull-Up Input
Test Pull Up Resistance Value: 41.0k ohms
Above results for Pin ID PA4

Test 3: Pull-Up Input
Test Pull Up Resistance Value: 41.0k ohms
Above results for Pin ID PA1

Test 3: Pull-Up Input
Test Pull Up Resistance Value: 41.0k ohms
Above results for Pin ID PB4

Test 3: Pull-Up Input
Test Pull Up Resistance Value: 41.0k ohms
Above results for Pin ID PB14

Test 3: Pull-Up Input
Test Pull Up Resistance Value: 41.0k ohms
Above results for Pin ID PB10

Test 3: Pull-Up Input
Test Pull Up Resistance Value: 41.0k ohms
Above results for Pin ID PB15

Test 3: Pull-Up Input
Test Pull Up Resistance Value: 41.0k ohms
Above results for Pin ID PC2

Test 3: Pull-Up Input
Test Pull Up Resistance Value: 41.0k ohms
Above results for Pin ID PC1

Test 3: Pull-Up Input
Test Pull Up Resistance Value: 41.0k ohms
Above results for Pin ID PB0

Test 3: Pull-Up Input
Test Pull Up Resistance Value: 41.0k ohms
Above results for Pin ID PB3

Test 3: Pull-Up Input
Test Pull Up Resistance Value: 41.0k ohms
Above results for Pin ID PB5

Test 3: Pull-Up Input
Test Pull Up Resistance Value: 41.0k ohms
Above results for Pin ID PB13

Test 3: Pull-Up Input
Test Pull Up Resistance Value: 41.0k ohms
Above results for Pin ID PC3

Test 3: Pull-Up Input
Test Pull Up Resistance Value: 41.0k ohms
Above results for Pin ID PC0

Test 3: Pull-Up Input
Test Pull Up Resistance Value: 9.0k ohms
Above results for Pin ID PA10

Test 3: Pull-Up Input
Test Pull Up Resistance Value: 41.0k ohms
Above results for Pin ID PC4

Test 4: Pull-Down Input
Test Pull Down Resistance Value: 29.0k ohms
Above results for Pin ID PD2

Test 4: Pull-Down Input
Test Pull Down Resistance Value: 30.0k ohms
Above results for Pin ID PC12

Test 4: Pull-Down Input
Test Pull Down Resistance Value: 29.0k ohms
Above results for Pin ID PC11

Test 4: Pull-Down Input
Test Pull Down Resistance Value: 30.0k ohms
Above results for Pin ID PC10

Test 4: Pull-Down Input
Test Pull Down Resistance Value: 29.0k ohms
Above results for Pin ID PB8

Test 4: Pull-Down Input
Test Pull Down Resistance Value: 30.0k ohms
Above results for Pin ID PC6

Test 4: Pull-Down Input
Test Pull Down Resistance Value: 30.0k ohms
Above results for Pin ID PC9

Test 4: Pull-Down Input
Test Pull Down Resistance Value: 30.0k ohms
Above results for Pin ID PC8

Test 4: Pull-Down Input
Test Pull Down Resistance Value: 30.0k ohms
Above results for Pin ID PB9

Test 4: Pull-Down Input
Test Pull Down Resistance Value: 29.0k ohms
Above results for Pin ID PC5

Test 4: Pull-Down Input
Test Pull Down Resistance Value: 30.0k ohms
Above results for Pin ID PA6

Test 4: Pull-Down Input
Test Pull Down Resistance Value: 30.0k ohms
Above results for Pin ID PA11

Test 4: Pull-Down Input
Test Pull Down Resistance Value: 30.0k ohms
Above results for Pin ID PA12

Test 4: Pull-Down Input
Test Pull Down Resistance Value: 29.0k ohms
Above results for Pin ID PB7

Test 4: Pull-Down Input
Test Pull Down Resistance Value: 29.0k ohms
Above results for Pin ID PA15

Test 4: Pull-Down Input
Test Pull Down Resistance Value: 30.0k ohms
Above results for Pin ID PB2

Test 4: Pull-Down Input
Test Pull Down Resistance Value: 29.0k ohms
Above results for Pin ID PB6

Test 4: Pull-Down Input
Test Pull Down Resistance Value: 8.0k ohms
Above results for Pin ID PB12

Test 4: Pull-Down Input
Test Pull Down Resistance Value: 29.0k ohms
Above results for Pin ID PA7

Test 4: Pull-Down Input
Test Pull Down Resistance Value: 30.0k ohms
Above results for Pin ID PA0

Test 4: Pull-Down Input
Test Pull Down Resistance Value: 30.0k ohms
Above results for Pin ID PA8

Test 4: Pull-Down Input
Test Pull Down Resistance Value: 30.0k ohms
Above results for Pin ID PB1

Test 4: Pull-Down Input
Test Pull Down Resistance Value: 30.0k ohms
Above results for Pin ID PA9

Test 4: Pull-Down Input
Test Pull Down Resistance Value: 30.0k ohms
Above results for Pin ID PC7

Test 4: Pull-Down Input
Test Pull Down Resistance Value: 30.0k ohms
Above results for Pin ID PA4

Test 4: Pull-Down Input
Test Pull Down Resistance Value: 30.0k ohms
Above results for Pin ID PA1

Test 4: Pull-Down Input
Test Pull Down Resistance Value: 29.0k ohms
Above results for Pin ID PB4

Test 4: Pull-Down Input
Test Pull Down Resistance Value: 29.0k ohms
Above results for Pin ID PB14

Test 4: Pull-Down Input
Test Pull Down Resistance Value: 30.0k ohms
Above results for Pin ID PB10

Test 4: Pull-Down Input
Test Pull Down Resistance Value: 29.0k ohms
Above results for Pin ID PB15

Test 4: Pull-Down Input
Test Pull Down Resistance Value: 29.0k ohms
Above results for Pin ID PC2

Test 4: Pull-Down Input
Test Pull Down Resistance Value: 29.0k ohms
Above results for Pin ID PC1

Test 4: Pull-Down Input
Test Pull Down Resistance Value: 29.0k ohms
Above results for Pin ID PB0

Test 4: Pull-Down Input
Test Pull Down Resistance Value: 29.0k ohms
Above results for Pin ID PB3

Test 4: Pull-Down Input
Test Pull Down Resistance Value: 29.0k ohms
Above results for Pin ID PB5

Test 4: Pull-Down Input
Test Pull Down Resistance Value: 29.0k ohms
Above results for Pin ID PB13

Test 4: Pull-Down Input
Test Pull Down Resistance Value: 29.0k ohms
Above results for Pin ID PC3

Test 4: Pull-Down Input
Test Pull Down Resistance Value: 30.0k ohms
Above results for Pin ID PC0

Test 4: Pull-Down Input
Test Pull Down Resistance Value: 8.0k ohms
Above results for Pin ID PA10

Test 4: Pull-Down Input
Test Pull Down Resistance Value: 30.0k ohms
Above results for Pin ID PC4

Test 5: Input Logic
Logic High: 1
Logic Low: 0
Above results for Pin ID PD2

Test 5: Input Logic
Logic High: 1
Logic Low: 0
Above results for Pin ID PC12

Test 5: Input Logic
Logic High: 1
Logic Low: 0
Above results for Pin ID PC11

Test 5: Input Logic
Logic High: 1
Logic Low: 0
Above results for Pin ID PC10

Test 5: Input Logic
Logic High: 1
Logic Low: 0
Above results for Pin ID PB8

Test 5: Input Logic
Logic High: 1
Logic Low: 0
Above results for Pin ID PC6

Test 5: Input Logic
Logic High: 1
Logic Low: 0
Above results for Pin ID PC9

Test 5: Input Logic
Logic High: 1
Logic Low: 0
Above results for Pin ID PC8

Test 5: Input Logic
Logic High: 1
Logic Low: 0
Above results for Pin ID PB9

Test 5: Input Logic
Logic High: 1
Logic Low: 0
Above results for Pin ID PC5

Test 5: Input Logic
Logic High: 1
Logic Low: 0
Above results for Pin ID PA6

Test 5: Input Logic
Logic High: 1
Logic Low: 0
Above results for Pin ID PA11

Test 5: Input Logic
Logic High: 1
Logic Low: 0
Above results for Pin ID PA5

Test 5: Input Logic
Logic High: 1
Logic Low: 0
Above results for Pin ID PA12

Test 5: Input Logic
Logic High: 1
Logic Low: 0
Above results for Pin ID PC13

Test 5: Input Logic
Logic High: 1
Logic Low: 0
Above results for Pin ID PB7

Test 5: Input Logic
Logic High: 1
Logic Low: 0
Above results for Pin ID PA15

Test 5: Input Logic
Logic High: 1
Logic Low: 0
Above results for Pin ID PB2

Test 5: Input Logic
Logic High: 1
Logic Low: 0
Above results for Pin ID PB6

Test 5: Input Logic
Logic High: 1
Logic Low: 0
Above results for Pin ID PB12

Test 5: Input Logic
Logic High: 1
Logic Low: 0
Above results for Pin ID PA7

Test 5: Input Logic
Logic High: 1
Logic Low: 0
Above results for Pin ID PA0

Test 5: Input Logic
Logic High: 1
Logic Low: 0
Above results for Pin ID PA8

Test 5: Input Logic
Logic High: 1
Logic Low: 0
Above results for Pin ID PB1

Test 5: Input Logic
Logic High: 1
Logic Low: 0
Above results for Pin ID PA9

Test 5: Input Logic
Logic High: 1
Logic Low: 0
Above results for Pin ID PC7

Test 5: Input Logic
Logic High: 1
Logic Low: 0
Above results for Pin ID PA4

Test 5: Input Logic
Logic High: 1
Logic Low: 0
Above results for Pin ID PA1

Test 5: Input Logic
Logic High: 1
Logic Low: 0
Above results for Pin ID PB4

Test 5: Input Logic
Logic High: 1
Logic Low: 0
Above results for Pin ID PB14

Test 5: Input Logic
Logic High: 1
Logic Low: 0
Above results for Pin ID PB10

Test 5: Input Logic
Logic High: 1
Logic Low: 0
Above results for Pin ID PB15

Test 5: Input Logic
Logic High: 1
Logic Low: 0
Above results for Pin ID PC2

Test 5: Input Logic
Logic High: 1
Logic Low: 0
Above results for Pin ID PC1

Test 5: Input Logic
Logic High: 1
Logic Low: 0
Above results for Pin ID PB0

Test 5: Input Logic
Logic High: 1
Logic Low: 0
Above results for Pin ID PB3

Test 5: Input Logic
Logic High: 1
Logic Low: 0
Above results for Pin ID PB5

Test 5: Input Logic
Logic High: 1
Logic Low: 0
Above results for Pin ID PB13

Test 5: Input Logic
Logic High: 1
Logic Low: 0
Above results for Pin ID PC3

Test 5: Input Logic
Logic High: 1
Logic Low: 0
Above results for Pin ID PC0

Test 5: Input Logic
Logic High: 1
Logic Low: 0
Above results for Pin ID PA10

Test 5: Input Logic
Logic High: 1
Logic Low: 0
Above results for Pin ID PC4

Test 6: ADC Check
ADC Return Value: 1: 3.2
ADC Return Value: 2: 1.5
ADC Return Value: 3: 0.0
Above results for Pin ID PC4

Test 6: ADC Check
ADC Return Value: 1: 3.2
ADC Return Value: 2: 1.5
ADC Return Value: 3: 0.0
Above results for Pin ID PC5

Test 6: ADC Check
ADC Return Value: 1: 3.2
ADC Return Value: 2: 1.5
ADC Return Value: 3: 0.0
Above results for Pin ID PB1

Test 6: ADC Check
ADC Return Value: 1: 3.2
ADC Return Value: 2: 1.5
ADC Return Value: 3: 0.0
Above results for Pin ID PC2

Test 6: ADC Check
ADC Return Value: 1: 3.2
ADC Return Value: 2: 1.5
ADC Return Value: 3: 0.0
Above results for Pin ID PC3

Test 6: ADC Check
ADC Return Value: 1: 3.2
ADC Return Value: 2: 1.5
ADC Return Value: 3: 0.0
Above results for Pin ID PA0

Test 6: ADC Check
ADC Return Value: 1: 3.2
ADC Return Value: 2: 1.5
ADC Return Value: 3: 0.0
Above results for Pin ID PA1

Test 6: ADC Check
ADC Return Value: 1: 3.2
ADC Return Value: 2: 1.5
ADC Return Value: 3: 0.0
Above results for Pin ID PA4

Test 6: ADC Check
ADC Return Value: 1: 3.2
ADC Return Value: 2: 1.5
ADC Return Value: 3: 0.0
Above results for Pin ID PB0

Test 6: ADC Check
ADC Return Value: 1: 3.2
ADC Return Value: 2: 1.5
ADC Return Value: 3: 0.0
Above results for Pin ID PC1

Test 6: ADC Check
ADC Return Value: 1: 3.2
ADC Return Value: 2: 1.5
ADC Return Value: 3: 0.0
Above results for Pin ID PC0

Above results for Pin ID None

Test 7: Set Power Mode
Current in mA Before Power Mode: 70.17
Current in mA After Power Mode: 60.59
Above results for Pin ID PD2

Test 8: Wakeup From Sleep
Current in mA Before Wakeup: 60.0
Current in mA After Wakeup: 69.8
Above results for Pin ID PD2

Test 7: Set Power Mode
Current in mA Before Power Mode: 69.97
Current in mA After Power Mode: 54.34
Above results for Pin ID PC12

Test 8: Wakeup From Sleep
Current in mA Before Wakeup: 54.5
Current in mA After Wakeup: 70.2
Above results for Pin ID PC12

Test 7: Set Power Mode
Current in mA Before Power Mode: 69.97
Current in mA After Power Mode: 50.24
Above results for Pin ID PC11

Test 8: Wakeup From Sleep
Current in mA Before Wakeup: 50.2
Current in mA After Wakeup: 69.8
Above results for Pin ID PC11

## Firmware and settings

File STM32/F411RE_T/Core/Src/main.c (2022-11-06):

/**
  ******************************************************************************
  * @file           : main.c
  * @brief          : Main program body
  * @author			: Nathan Hanchey
  ******************************************************************************
  * @attention
  *
  * Copyright (c) 2022 STMicroelectronics.
  * All rights reserved.
  *
  * This software is licensed under terms that can be found in the LICENSE file
  * in the root directory of this software component.
  * If no LICENSE file comes with this software, it is provided AS-IS.
  *
  * References:
  * STM32 Arm Programming For Embedded Systems
  * Authors: Muhammad Ali Mazidi | Shujen Chen | Eshragh Ghaemi
  ******************************************************************************
  */
/* USER CODE END Header */
/* Includes ------------------------------------------------------------------*/
#include "main.h"
#include "setup.h"
#include <string.h>

#define CRC_KEY 5

/* USER CODE BEGIN Includes */


 ADC_HandleTypeDef hadc1;

UART_HandleTypeDef huart2;

void SystemClock_Config(void);
static void MX_GPIO_Init(void);
static void MX_USART2_UART_Init(void);
static void MX_ADC1_Init(void);
/* USER CODE BEGIN PFP */

// SERIAL
int command_read(unsigned char data[]);
int command_write(unsigned int pin, unsigned int result, unsigned int test);
int crc_encode(unsigned char data[], unsigned int pin, unsigned int result, unsigned int test);
int crc_decode(unsigned char data[]);

/* Config Function Prototypes */
void configure_output(unsigned int pin, unsigned int logic);
int configure_input(unsigned int pin);
void configure_input_pullup(unsigned int pin);
int configure_analog_input(unsigned int pin);
void configure_input_pulldown(unsigned int pin);
void configure_sleep_mode(unsigned int sleepmode, unsigned int interruptPin);
void wakeUp();

//IO SIGNALS
struct pin PINS_[64];
int analogRead(int pin);
int digitalRead(int pin);
void analogWrite(int pin, int value);
void digitalWrite(int pin, int logic);
void pinMode(int pin, int mode);
void reset_pins();


//FIX AFTER ARDUINO PORTION
void run_tests(unsigned char data[]);
int sleepmode(int mode);

//https://thekurks.net/blog/2018/1/24/guide-to-arduino-sleep-mode
//void attachInterrupt();
//void set_sleep_mode();
//void sleep_cpu();




UART_HandleTypeDef huart2;



/**
  * @brief  The application entry point.
  * @retval int
  */
int main(void) {

	/* MCU Configuration----------------------------------------------------------*/
	/* Reset of all peripherals, Initializes the Flash interface and the Systick. */
	HAL_Init();
	SystemClock_Config();
	/* Initialize all configured peripherals */
	MX_GPIO_Init();
	MX_USART2_UART_Init();
	MX_ADC1_Init();

	//IO INITs
	init_pins(PINS_);

	// pinMode(0, OUTPUT);
	// digitalWrite(0, HIGH);

    while (1) {

    	//USART2->;
  	  if(__HAL_UART_GET_FLAG(&huart2, UART_FLAG_RXNE)) {

  		    //Write Test
    		uint8_t RMSG[3] = {0};
  			command_read(RMSG);
  			delay(50);	//delay is important

  			if(crc_decode(RMSG) && RMSG[0] > 0){

  				//Interpret Instructions
  				if (RMSG[1] < 128) {
  					run_tests(RMSG);
  				}
  				else {
  					RMSG[0] = PINS_[RMSG[0]].pin;
  				}

  			}

  	  }
    }

  /* USER CODE END 3 */
}


/********************************************************/
//Tests
/********************************************************/
void run_tests(unsigned char data[]) {

	unsigned char pin = data[0];
	unsigned char instruction = data[1];

	// Test #1
	if(data[2] == 1) {
		/*
		if(instruction == 1) {
			pinMode(pin, OUTPUT);
			digitalWrite(pin, 1);
		}
		else if(instruction == 0) {
			pinMode(pin, OUTPUT);
			digitalWrite(pin, 0);
		}
		*/
		//reset_pins();
		configure_output(pin, instruction);
		command_write(data[0], data[1], data[2]);

	}
	else if(data[2] == 2) {
		//reset_pins();
		configure_output(pin, instruction);
		command_write(data[0], data[1], data[2]);
	}
	else if(data[2] == 3) {
		//reset_pins();
		configure_input_pullup(pin);
		command_write(data[0], data[1], data[2]);
	}
	else if(data[2] == 4) {
		configure_input_pulldown(pin);
		command_write(data[0], data[1], data[2]);
	}
	else if(data[2] == 5) {
		data[1] = configure_input(pin);
		command_write(data[0], data[1], data[2]);
	}
	else if(data[2] == 6) {
		data[1] = configure_analog_input(pin);
		command_write(data[0], data[1], data[2]);
	}
	else if(data[2] == 7) {
		if(instruction == 1) {
			configure_sleep_mode(1, pin);
		}
		else if(instruction == 2) {
			configure_sleep_mode(2, pin);
		}
		else if(instruction == 3) {
			configure_sleep_mode(4, pin);
		}

	}
	else {
		command_write(data[0], data[1], data[2]);
	}

}


/********************************************************/
// Value Getters
/********************************************************/
/*
 * Description: Configures GPIO pin as OUTPUT and turns the output to HIGH. Used for testing GPIO output voltage under load sourcing.
 * Accepts: unsigned int pin - the pin number to configure as OUTPUT
 *          unsigned int logic - HIGH or LOW logic
 * Returns: void
 */
void configure_output(unsigned int pin, unsigned int logic) {
    pinMode(pin, OUTPUT);
    if(logic) {
      digitalWrite(pin, HIGH);
    }
    else {
      digitalWrite(pin, LOW);
    }
    return;
}

/*FIX The digitalREAD!
 * Description: Configures GPIO pin as an INPUT. Used for testing input logic levels. The input pin cannot be a pullup,
 * as that would allow the pin to act as a current source and could damage the testing device's DAC.
 * Accepts: unsigned int pin - the pin number to configure as INPUT
 * Returns: int - 0 or 1 depending on input voltage of the pin (LOGIC LOW OR HIGH)
 */
int configure_input(unsigned int pin) {
    pinMode(pin, INPUT);
    return digitalRead(pin);
}

/*
 * Description: Configures GPIO pin as INPUT_PULLUP. Used for testing the pin's unloaded pullup voltage and internal
 * resistance value.
 * Accepts: unsigned int pin - the pin number to configure as INPUT_PULLUP
 * Returns: void
 */
void configure_input_pullup(unsigned int pin) {
    pinMode(pin,INPUT_PULLUP);
    return;
}

/*
 * Description: Configures GPIO pin as INPUT_PULLDOWN. Used for testing the pin's unloaded pullup voltage and internal
 * resistance value.
 * Accepts: unsigned int pin - the pin number to configure as INPUT_PULLDOWN
 * Returns: void
 */
void configure_input_pulldown(unsigned int pin) {
    pinMode(pin,INPUT_PULLDOWN);
    return;
}


/* FIX
 * Description: Returns the analog reading of the selected analog pin (A0, A1, ..., A5). Used for testing the Arduino's
 * ADC.
 * Accepts: unsigned int analogPin - the analog pin number to read
 * Returns: int - 0 to 1023, depending on the voltage reading of the ADC. (0 = GND, 1023 = 5V)
 */
int configure_analog_input(unsigned int analogPin) {
	pinMode(analogPin, INPUT);
   return (analogRead(analogPin) >> 4); //returns a value 0- (0=GND,  = 3V3)
}




/********************************************************/
//IO  Sleep Modes / PINS
/********************************************************/

void HAL_GPIO_EXTI_Callback(uint16_t GPIO_pin) {
	SystemClock_Config();
	HAL_PWR_DisableSleepOnExit();
	//HAL_GPIO_WritePin(GPIOA, GPIO_PIN_5, GPIO_PIN_SET);
	HAL_ResumeTick();
}

//
void configure_sleep_mode(unsigned int mode, unsigned int interruptPin) {

	// SLEEP == 1
	MX_GPIO_Init();
	SystemClock_Config();
	// Wake Up = ?PA0 | D13
	if(mode == 1) {
		HAL_PWR_EnableSEVOnPend();
		wakeUp(interruptPin);
		HAL_SuspendTick();
		HAL_PWR_EnterSLEEPMode(PWR_MAINREGULATOR_ON, PWR_SLEEPENTRY_WFE);
		HAL_ResumeTick();
	}
	// STOP == 2
	// Wake Up = Reset
	else if(mode == 2) {
		HAL_PWR_EnableSEVOnPend();
		__HAL_PWR_CLEAR_FLAG(PWR_FLAG_WU);
		//wakeUp(interruptPin);
		HAL_SuspendTick();
		HAL_PWR_EnableWakeUpPin(PWR_WAKEUP_PIN1);

		HAL_PWR_EnterSTOPMode(PWR_MAINREGULATOR_ON, PWR_SLEEPENTRY_WFI);
		HAL_ResumeTick();
	}
	// STANDBY == 4
	// Wake up Pin1 = PA0 | Pin2 = PC13
	else if(mode == 4) {
		__HAL_PWR_CLEAR_FLAG(PWR_FLAG_WU);
		if(interruptPin == 1) {
			HAL_PWR_EnableWakeUpPin(PWR_WAKEUP_PIN1);
		}
		//else if (interruptPin == 2) {
		//	HAL_PWR_EnableWakeUpPin(PWR_WAKEUP_PIN2);
		//}
		else {
			HAL_PWR_EnableWakeUpPin(PWR_WAKEUP_PIN1);
		}
		HAL_PWR_EnterSTANDBYMode();
	}

}

// EXTI Interrupt Function
void wakeUp(int pin) {
		__disable_irq();

		// Pin A0
		GPIO_InitTypeDef GPIO_InitStruct = {0};
		/*Configure GPIO pin : PA0 */
		GPIO_InitStruct.Pin = GPIO_PIN_0;
		GPIO_InitStruct.Mode = GPIO_MODE_IT_RISING;
		GPIO_InitStruct.Pull = GPIO_NOPULL;
		HAL_GPIO_Init(GPIOA, &GPIO_InitStruct);


		/* EXTI interrupt init*/
		HAL_NVIC_SetPriority(EXTI0_IRQn, 0, 0);
		HAL_NVIC_EnableIRQ(EXTI0_IRQn);
		__enable_irq();
}


void EXTI15_10_IRQHandler(void) {
	//HAL_GPIO_WritePin(GPIOA, GPIO_PIN_5, GPIO_PIN_SET);
	if(EXTI->PR == 0x2000) {
		HAL_ResumeTick();
		EXTI->PR = 0x2000;
	}
	else if(EXTI->PR == 0x0001) {
		HAL_ResumeTick();
		EXTI->PR = 0x0001;
	}
	SystemClock_Config();
	HAL_PWR_DisableSleepOnExit();
	HAL_ResumeTick();
	EXTI->PR = 0x0001;
}


/********************************************************/
// Read & Write Functions
/********************************************************/

int analogRead(int pin) { //!IN PROGRESS [NEED TO DEVELOP DEBUGGING METHOD]

	int result, channel = 0;
	//SET REGESTERS p213

	//ANALOG MAPPING
	if(PINS_[pin].clock == 1) {
		channel = PINS_[pin].pin;
	}
	else if(PINS_[pin].clock == 2) {
		channel = PINS_[pin].pin + 8;
	}
	else if(PINS_[pin].clock == 4) {
		channel = PINS_[pin].pin + 10;
	}

	//Pin Setup
	RCC->AHB1ENR |= PINS_[pin].clock;  //clock for pin
	PINS_[pin].GPIO->MODER |= (0x03 << (PINS_[pin].pin * 2)); // Set to ADC mode

	//ADC1
	RCC->APB2ENR |= 0x00000100; /* Enable ADC1 clock */
	/* Setup for ACD1 */
	ADC1->CR2 = 0;
	ADC1->SQR3 = channel;
	ADC1->SQR1 = 0;
	ADC1->CR2 |= 1;

	//FIND VALUE in ADC1
	ADC1->CR2 |= 0x40000000;
	while(!(ADC1->SR & 2)) {}
	result = ADC1->DR;

	return result;
}

void pinMode(int pin, int mode) {

	if(mode == INPUT_PULLUP) { //P
		RCC->AHB1ENR |= PINS_[pin].clock;
		PINS_[pin].GPIO->MODER &= ~(0x03 << (PINS_[pin].pin * 2)); 		/* Clear Mode to Input */
		PINS_[pin].GPIO->PUPDR &= ~(0x03 << (PINS_[pin].pin * 2)); 	/* Enable Pull-up resister by setting bit 0x01 */
		PINS_[pin].GPIO->PUPDR |= (0x01 << (PINS_[pin].pin * 2));
	}
	else if(mode == INPUT_PULLDOWN) {
		RCC->AHB1ENR |= PINS_[pin].clock;
		PINS_[pin].GPIO->MODER &= ~(0x03 << (PINS_[pin].pin * 2)); 		/* Clear Mode to Input */
		PINS_[pin].GPIO->PUPDR &= ~(0x03 << (PINS_[pin].pin * 2)); 	/* Enable Pull-down resister by setting bit 0x02 */
		PINS_[pin].GPIO->PUPDR |= (0x02 << (PINS_[pin].pin * 2));
	}
	else if(mode == OUTPUT) {
		RCC->AHB1ENR |= PINS_[pin].clock; 							/* Enable Port Clock */
		(PINS_[pin].GPIO)->MODER &= ~(0x03 << (PINS_[pin].pin * 2)); 		/* Clear Mode */
		(PINS_[pin].GPIO)->MODER |= (0x01 << (PINS_[pin].pin * 2));			/* Set Mode to Output */
	}
	else {
		RCC->AHB1ENR |= PINS_[pin].clock;
		PINS_[pin].GPIO->MODER &= ~(0x03 << (PINS_[pin].pin * 2)); 		/* Clear Mode to Input */
		PINS_[pin].GPIO->PUPDR &= ~(0x03 << (PINS_[pin].pin * 2)); 	/* Enable Floating by setting bit 0x01 */
	}

}

int digitalRead(int pin_num) {

	//RCC->AHB1ENR |= PINS_[pin_num].clock;
	//PINS_[pin_num].GPIO->MODER &= ~PINS_[pin_num].pin_clear_mode; 	/* Clear Mode to Input */
	//PINS_[pin_num].GPIO->PUPDR |= 0x00 << (PINS_[pin_num].pin * 2); 	/* Enable Pull-up resister by setting bit 0x01 */

	int out = 0;

 	if(PINS_[pin_num].GPIO->IDR & (0x01 << PINS_[pin_num].pin)) {
 		out = 1;
 	}

	return out;
}


void digitalWrite(int pin, int logic) {
	//RCC->AHB1ENR |= PINS_[pin].clock; 						/* Enable Port Clock */
	//PINS_[pin].GPIO->MODER &= ~PINS_[pin].pin_clear_mode; 	/* Clear Mode */
	//PINS_[pin].GPIO->MODER |= PINS_[pin].pin_out_mode;		/* Set Mode to Output */

	if(logic) {
		PINS_[pin].GPIO->BSRR |= 0x01 << PINS_[pin].pin;
	}
	else {
		PINS_[pin].GPIO->BSRR |= 0x01 << (PINS_[pin].pin + 16);
	}

}

void reset_pins() {
	int i;
	for(i = 1; i < 63; i++) {
		configure_input(i);
	}
}

/********************************************************/
//SERIAL
/********************************************************/

int command_read(unsigned char data[]) {
	HAL_UART_Receive(&huart2, data, 3, 1000); //Changed from 10000 & while loop
	return 0;
}

int command_write(unsigned int pin, unsigned int result, unsigned int test) {
	//Write
	unsigned char data[3];
	crc_encode(data, pin, result, test);
	HAL_UART_Transmit(&huart2, data, 3, 1000); //changed from 100
	return 0;
}

int crc_encode(unsigned char data[], unsigned int pin, unsigned int result, unsigned int test) {
	// Find the data
	unsigned long int crc_packet = ((pin << 16) & 0xFF0000) + ((result << 8) & 0xFF00) + ((test << 4) & 0xF0);

	// Calculate CRC Number
	unsigned int remainder = crc_packet % CRC_KEY;
	unsigned int crc = CRC_KEY - remainder;

	crc_packet += crc;

	data[0] = ((crc_packet >> 16)) & 0xFF;
	data[1] = ((crc_packet >> 8)) & 0xFF;
	data[2] = ((crc_packet) & 0xFF);

	return 0;
}


int crc_decode(unsigned char data[]) {

	// Find the data
	unsigned long int crc_packet = (((unsigned long int)data[0] << 16) & 0xFF0000)
			+ (((unsigned long int)data[1] << 8) & 0xFF00) + (((unsigned long int)data[2]));

	if(crc_packet % CRC_KEY) {
		return 0;
	}

	data[2] = (data[2] & 0xF0) >> 4;

	return 1;
}


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


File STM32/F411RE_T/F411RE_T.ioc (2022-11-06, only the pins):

Mcu.UserName=STM32F411RETx
PA0-WKUP.Signal=GPXTI0
PA1.Signal=ADCx_IN1
PA13.GPIO_Label=TMS
PA13.Signal=SYS_JTMS-SWDIO
PA14.GPIO_Label=TCK
PA14.Signal=SYS_JTCK-SWCLK
PA2.GPIO_Label=USART_TX
PA2.Signal=USART2_TX
PA3.GPIO_Label=USART_RX
PA3.Signal=USART2_RX
PA4.Signal=ADCx_IN4
PA5.GPIO_Label=LD2 [Green Led]
PA5.Signal=GPIO_Output
PA6.Signal=ADCx_IN6
PA7.Signal=ADCx_IN7
PB0.Signal=ADCx_IN8
PB1.Signal=ADCx_IN9
PB3.GPIO_Label=SWO
PB3.Signal=SYS_JTDO-SWO
PC0.Signal=ADCx_IN10
PC1.Signal=ADCx_IN11
PC13-ANTI_TAMP.GPIO_Label=B1 [Blue PushButton]
PC13-ANTI_TAMP.Signal=GPXTI13
PC14-OSC32_IN.Signal=RCC_OSC32_IN
PC15-OSC32_OUT.Signal=RCC_OSC32_OUT
PC2.Signal=ADCx_IN12
PC3.Signal=ADCx_IN13
PC4.Signal=ADCx_IN14
PC5.Signal=ADCx_IN15

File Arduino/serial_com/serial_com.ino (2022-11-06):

/************************************************************
 * Description: Serial Communication to Raspi Test
 * Author:  Nathan Hanchey
            Dylan Vetter
            Corey Moura
            Connor Inglat
 * Date: May 17th 2022
 ************************************************************/

/* Libraries */
#include <avr/sleep.h> //Contains the methods used to control the sleep modes

/* Function Prototypes */
void command_read(unsigned char data[]);
void command_write(unsigned int pin, unsigned int result, unsigned int test);
void crc_encode(unsigned char data[], unsigned int pin, unsigned int result, unsigned int test);
int crc_decode(unsigned char data[]);

/* Config Function Prototypes */
void configure_output(unsigned int pin, unsigned int logic);
int configure_input(unsigned int pin);
void configure_input_pullup(unsigned int pin);
int configure_analog_input(unsigned int pin);
void configure_sleep_mode(unsigned int sleepmode, unsigned int interruptPin);
void wakeUp();

struct pin pin_set(uint32_t pin, uint8_t pin_id);
void init_pins(struct pin pins[]);
void reset_pins();
void reset_pins_pullup();

/* Pin Struct */
struct pin {
  uint32_t pin;
  uint8_t pin_id;
};

/* Global Variables */
unsigned char RMSG[3];
unsigned int test_result;
unsigned int pin_num;
unsigned int facade_test = 0;
struct pin PINS_[64];

/* Runs once upon startup of the program */
void setup() {

    Serial.begin(115200); //sets the baud rate
    while (!Serial) {
        ; // wait for serial port to connect. Needed for native USB port only
    }

    //+Sleep Modes

    init_pins(PINS_);
}


/* Runs repeatedly after setup has completed */
void loop() {

    if (Serial.available() > 0) { //Serial.available() returns the number of bytes read
        delay(50); //NEEDED
        
        //Write Test
        command_read(RMSG);

        if(crc_decode(RMSG)){
            //Interpret Instructions
            //RMSG[0] = pin under test, RMSG[1] = Special Instructions, RMSG[2] = Test Identification
            unsigned int pin_val = PINS_[RMSG[0]].pin;

            //Adjust Pin Control Functions when in Facade Mode
            //Make Conditional for Facade
            if(RMSG[1] >= 128) {
              facade_test = 1;
            }
            else {
              facade_test = 0;
            }
              
            switch (RMSG[2]) { // Test Identification #
                case 1: 
                    if(facade_test) {
                        RMSG[0] = (unsigned char)pin_val;
                        RMSG[1] = (unsigned char)0;
                    }
                    else {
                        //reset_pins();
                        configure_output(pin_val, RMSG[1]); 
                    }
                    command_write(RMSG[0], RMSG[1], RMSG[2]);
                    break;
                case 2:
                    if(facade_test) {
                        RMSG[0] = pin_val;
                        RMSG[1] = 2;
                    }
                    else {
                        //reset_pins();
                        configure_output(pin_val, RMSG[1]);
                    }
                    command_write(RMSG[0], RMSG[1], RMSG[2]);
                    break;
                case 3:
                    if(facade_test) {
                        RMSG[0] = pin_val;
                        RMSG[1] = 3;
                    }
                    else {
                      //reset_pins();
                      configure_input_pullup(pin_val);
                    }
                    command_write(RMSG[0], RMSG[1], RMSG[2]);
                    break;
                case 4:
                    // configure pull down (does not exist for arduino)
                    command_write(RMSG[0], RMSG[1], RMSG[2]);
                    break;
                case 5:
                    if(facade_test) {
                        RMSG[0] = pin_val;
                        RMSG[1] = 5;
                        command_write(RMSG[0], RMSG[1], RMSG[2]);
                    }
                    else {
                      test_result = configure_input(pin_val);
                      command_write(RMSG[0], test_result, RMSG[2]);
                    }
                    
                    break;
                case 6:
                    if(facade_test) {
                        RMSG[0] = pin_val;
                        RMSG[1] = 6;
                        command_write(RMSG[0], RMSG[1], RMSG[2]);
                    }
                    else {
                      //reset_pins_pullup();
                      test_result = configure_analog_input(pin_val);
                      command_write(RMSG[0], test_result, RMSG[2]);

                      // Reconfigure Pin Setup
                      configure_input(pin_val);
                    }
                    break;
                case 7:
                    if(facade_test) {
                        RMSG[0] = pin_val;
                        RMSG[1] = 7;
                    }
                    else {
                      configure_sleep_mode(RMSG[1], RMSG[0]); //send sleepmode & pin#
                      //command_write(RMSG[0], RMSG[1], RMSG[2]);
                    }
                    break;
                    
                default:
                    command_write(RMSG[0], RMSG[1], RMSG[2]);
                    break;
            }

        }
        else {
          //command_write(RMSG[0], RMSG[1], RMSG[2]);
        }
    }

}

/*
 * Description: Reads the next three bytes from the serial communication port and stores them into the data array
 * Accepts: unsigned char data[] - the data array used to store the read data
 * Returns: void
 */
void command_read(unsigned char data[]) {
    //HAL_UART_Receive(&huart2, data, 3, 10000); //On STM
    data[0] = Serial.read(); //Serial.read() returns the first available byte in the serial buffer, then removes it.
    data[1] = Serial.read();
    data[2] = Serial.read();

    return;
}

/*
 * Description: Calls the crc_encode function then writes the resulting encoded bytes to the serial communication port
 * Accepts: unsigned int pin - the pin number to encode and send
 *          unsigned int result - the result of the test to encode and send
 *          unsigned int test - the test number to encode and send
 * Returns: void
 */
void command_write(unsigned int pin, unsigned int result, unsigned int test) {

    //Write
    unsigned char data[3];

    crc_encode(data, pin, result, test);

    //HAL_UART_Transmit(&huart2, data, 3, 100); // On STM
    Serial.write(data[0]); //Serial.write(x) writes binary data to the serial port as a byte or series of bytes
    Serial.write(data[1]);
    Serial.write(data[2]);

    return;
}
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
